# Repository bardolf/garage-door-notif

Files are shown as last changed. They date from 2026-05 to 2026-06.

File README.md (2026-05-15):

# Garage door notif

Battery-powered detekce otevřených garážových vrat v noci (22:00–06:00) přes ESP32 + MPU6050 + ntfy.sh push notifikace. Cílová životnost na 18650 baterii: **~1 rok mezi nabíjeními** (omezeno self-discharge baterky ~2–4 %/měsíc + kapacitní degradace + chlad v garáži, ne čistou spotřebou ESP).

**Dokumentace:**
- [`USAGE.md`](USAGE.md) — pro koncového uživatele (jak to funguje, co znamenají notifikace, FAQ)

---

## Use case

**Co řešíme:** Detekovat, jestli jsou garážová vrata **otevřená v noci mezi 22:00 a 06:00**, a poslat alert na mobil.

**Klíčový rozdíl proti motion detekci:** vrata mohou být otevřená už od 14:00 a zůstat tak — v 22:00 už žádný motion event nenastane. **Musíme polovat stav, ne čekat na změnu.**

**Design cíle:**
- Alert do ~5 min po 22:00, pokud jsou vrata otevřená
- Alert i během noci, pokud se otevřou
- Battery-powered, žádné kabelování ke garáži
- Životnost **~1 rok** mezi nabíjeními (realistický cíl, ne teoretické maximum)
- Žádný „false positive" z větru / vibrací

---

## Architektura

Timer-based polling (ne motion-driven). ESP probudí RTC každých 5 min, přečte tilt z MPU6050, rozhodne na základě času a stavu, případně pošle notifikaci, vrátí se do deep sleep.

```
COLD BOOT (power-on / RST)
   │
   ├─► WiFi + NTP sync
   ├─► MPU baseline capture (50 vzorků, průměr — předpoklad: vrata zavřená)
   ├─► Boot notifikace na ntfy.sh
   └─► ESP+MPU deep sleep, wake za 5 min
                    │
                    ▼
WAKE CYCLE (každých 5 min)
   │
   ├─► Wake MPU přes I²C (clear SLEEP bit, wait 30 ms)
   ├─► Read accel × 6 (zahod první, průměr ze zbylých 5)
   ├─► Spočti tilt vůči baseline (3D úhel)
   ├─► MPU zpět do SLEEP mode (5 µA)
   │
   ├─► Hystereze: open >60°, close <40° (stav v RTC mem)
   │
   ├─► Časová logika:
   │     ├─ 22:00-06:00 + open + rate limit OK (4 min) → URGENT alert
   │     ├─ hodina 21 + heartbeat dnes neodeslán      → daily heartbeat
   │     ├─ poslední NTP sync >24h                    → opportunistic refresh
   │     └─ MPU error queue má pendingy               → error report
   │
   ├─► Pokud potřeba WiFi: connect → ntp_sync (zadarmo) → poslat → disconnect
   └─► ESP+MPU deep sleep, wake za 5 min
```

### Klíčové principy

1. **Timer wake (RTC), ne motion wake (MPU INT)** — vrata stojí staticky, motion event se nestane.
2. **MPU drží v SLEEP mode (5 µA) mezi měřeními** — ESP probudí přes I²C jen na ~50 ms při wake.
3. **Hystereze + průměr** — proti vibracím / větru. První sample po wake je outlier (zahodit).
4. **Rate limiting alertů 4 min** — pri stuck-open vratech alert každý wake cyklus (~5 min), neoslepí appku ale informuje opakovaně.
5. **NTP sync 1× za 24 h + opportunistic** — pokaždé když už máme WiFi (alert/heartbeat), syncneme i čas zadarmo.
6. **State v RTC slow memory** — baseline, alert/heartbeat trackery, error queue, hysteresis stav přežívají deep sleep, ne power-off.
7. **Errors přes ntfy** — jediný komunikační kanál, takže senzor failures se queueují a posílají při příští WiFi příležitosti.

---

## Hardware

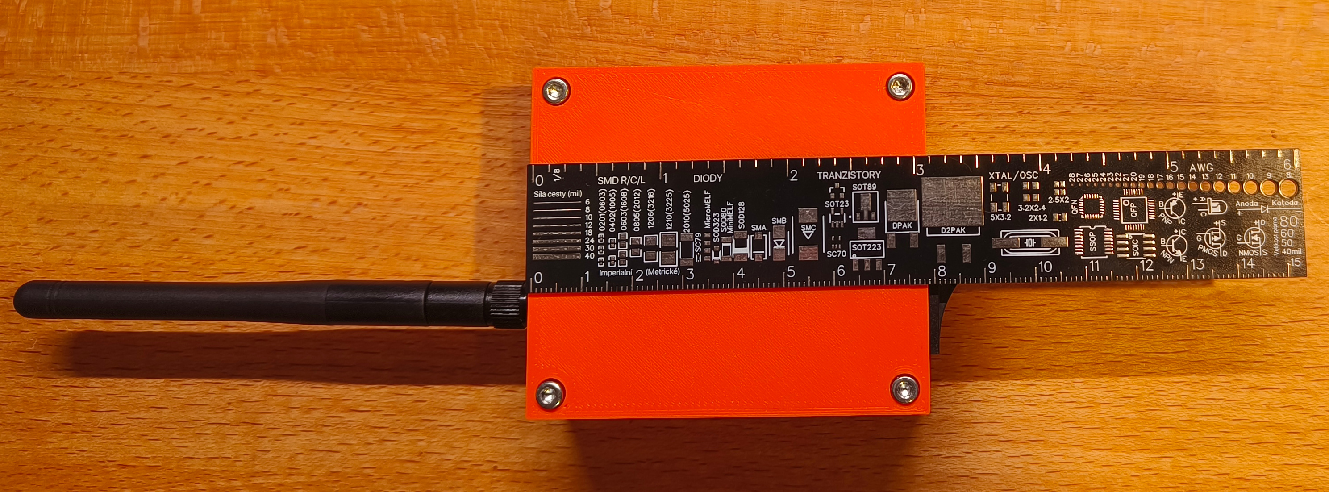
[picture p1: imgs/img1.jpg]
Hotová krabička s externí anténou vedle pravítka pro měřítko


*Hotové zařízení (varianta s externí anténou) — 3D tištěná krabička 7×8×3 cm, vlevo viditelná externí anténa 2,4 GHz na pigtailu.*

> **Pozor — LaskaKit ESP32-C3-LPKit v4 existuje ve dvou variantách:**
> 1. **S integrovanou PCB anténou** — plug-and-play, stačí samotná deska. Vhodné pokud AP je v rozumné vzdálenosti (~10 m, přes 1 zeď).
> 2. **S u.FL/IPEX konektorem pro externí anténu** — bez antény nepřijímá WiFi! Nutné dokoupit **pigtail U.FL ↔ SMA** + **externí anténu 2,4 GHz** (řádky níže v BOM). Větší dosah, vhodné kdy AP přes víc zdí nebo dál.
>
> Při objednávce ověřit kterou variantu máš — popis na LaskaKit produktové stránce nemusí být jednoznačný, podle revize. Pokud nevíš, podívej se na fotku desky: PCB anténa = klikatý měděný motiv u rohu modulu; externí varianta má malý stříbrný konektor.

### BOM

| Položka | Cena | Pozn. |
|---|---:|---|
| **[LaskaKit ESP32-C3-LPKit v4](https://www.laskakit.cz/laskkit-esp-12-board/)** (board ID `esp32-c3-devkitm-1`) | 298 Kč | ESP32-C3 (RISC-V), nativní USB-CDC bez externího USB-Serial čipu, on-board WS2812 NeoPixel RGB LED (GPIO9), JST-PH 2.0 + integrovaný LiPo charger, low-quiescent LDO se softwarovým `PERIPH_EN` switchem (GPIO4) pro perif. rail. Sleep proud naměřeno **19 µA** — viz [Spotřeba](#spotřeba). Antenna varianta — viz poznámka nad tabulkou. |
| **[Pigtail U.FL ↔ SMA female, 15 cm](https://www.laskakit.cz/pigtail-u-fl-sma-female--kabel-1-13mm--15cm/)** *(jen u externí antény)* | 38 Kč | Propojení on-board U.FL/IPEX konektoru s externí anténou přes SMA spoj. Nutné jen u varianty desky bez integrované PCB antény. |
| **[Anténa 2,4 GHz 10 cm SMA](https://www.laskakit.cz/antena-10cm-2-4g/)** *(jen u externí antény)* | 88 Kč | NiceRF SW2400-ZD115. Šroubuje se na pigtail. Lepší dosah než on-board PCB anténa — vhodné pokud je AP daleko nebo přes zdi. |
| **[GY-521 MPU6050 / MPU6500](https://www.laskakit.cz/arduino-gyroskop-a-akcelerometr-gy-521--mpu6050/)** (akcelerometr) | 98 Kč | 6-axis IMU, I²C adresa `0x68`, on-board 3,3 V LDO + 4,7 kΩ pull-upy na SDA/SCL. Silkscreen říká „MPU6050", v praxi často osazeno **MPU-6500** (WHO_AM_I=0x70) — firmware detekuje a akceptuje obě varianty. Zelená status LED na modulu odpájet (1,44 mA always-on). |
| **[LaskKit GeB Li-Ion 18650 1S1P 3,7 V 3200 mAh](https://www.laskakit.cz/geb-li-ion-baterie-1x18650-1s1p-3-7v-3200mah/)** | 188 Kč | 18650 cell s integrovanou ochranou (over-discharge / over-current). Nabíjí se přes USB-C C3-LPKit (on-board charger). JST-PH 2.0 konektor. |
| **Spínač / tlačítko v sérii s baterií** | ~20 Kč | Rozepíná napájení z baterie — slouží k vynucenému cold bootu (zachycení nové baseline po instalaci, viz boot notifikace). Bez fyzického přístupu k RST tlačítku po zavření krabičky. |
| **Šroubky (M3 + M2)** | ~20 Kč | 4× M3 imbus pro víko krabičky + 2× M2 self-tap pro ESP modul + 2× M2 pro MPU. |
| **3D tištěná krabička** | ~30 Kč | OpenSCAD model `3dprint/`, průzor ve víku pro NeoPixel indikaci. MPU musí být pevně přichycena k vratům, ne k rámu (jinak měří pohyb rámu, ne dveří). Cena materiálu (PETG, ~60 g × ~0,5 Kč/g). |

Propojení MPU ↔ ESP: 4 drátky (VCC, GND, SDA, SCL) připájené přímo na pájecí pady — bez DuPont konektoru, pevnější vůči vibracím.

**Celkem:** ~660 Kč (s integrovanou PCB anténou) / ~790 Kč (s externí anténou).

### Pin allocation (LaskaKit ESP32-C3-LPKit v4 — aktuální)

| GPIO | Funkce | Pozn. |
|---|---|---|
| 0 | ADC — Vbat sense | on-board divider ×1.769, použít `analogReadMilliVolts()` (viz silkscreen v4.0) |
| 4 | `PERIPH_EN` — power switch perif. rail | HIGH = napájena MPU + NeoPixel; LOW = oboje off. `gpio_hold_en` pro persistenci přes deep sleep |
| 6 | I²C SDA → GY-521 SDA | volný GPIO bez kolize se strapping/USB/UART |
| 7 | I²C SCL → GY-521 SCL | volný GPIO bez kolize |
| 9 | on-board WS2812 NeoPixel (RGB LED) | jediný indikátor stavu; GPIO9 by jinak byl BOOT strapping, na C3-LPKit obsazený LED |
| 20 | UART0 RX | volné, lze využít pro externí USB-UART monitor při battery měření |
| 21 | UART0 TX | volné, lze využít pro externí USB-UART monitor při battery měření |

Obsazené čipem / deskou: USB-C přes nativní USB-CDC (GPIO18/19), 32 kHz krystal (interní RC), Flash (GPIO11–17 interní v ESP32-C3-MINI-1 modulu).

### Zapojení MPU6050 / MPU6500 ↔ ESP32-C3-LPKit v4

GY-521 modul napájíme **z PERIPH_EN railu** (přes GPIO4 power switch) — v deep sleep tak MPU dostane 0 V a nemusíme ji explicitně uspávat přes I²C kvůli sleep proudu.

| GY-521 pin | C3-LPKit pin | Pozn. |
|---|---|---|
| VCC | 3V3 | jakýkoli 3V3 pin na headeru — všechny jsou za PERIPH_EN switchem |
| GND | GND | jakýkoli GND pin |
| SDA | GPIO6 | I²C data |
| SCL | GPIO7 | I²C clock |
| AD0 | nezapojeno | → I²C adresa **0x68** (default pull-down na GY-521 modulu) |
| INT | nezapojeno | timer wake, ne motion interrupt |
| XCL, XDA | nezapojeno | aux I²C master pro magnetometr — nepoužívá se |

Pull-up rezistory pro I²C jsou integrované na GY-521 modulu (4.7 kΩ na SDA i SCL), externí netřeba.

**MPU chip:** silkscreen modulů obvykle říká `MPU6050`, ale GY-521 se prodávají s oběma — MPU-6050 (WHO_AM_I=0x68) i MPU-6500 (0x70). Firmware akceptuje 0x68/0x70/0x71/0x73 (MPU-6050/6500/9250/9255), register layout je v naší podmnožině (accel + temp) kompatibilní.

### Sestavení v krabičce

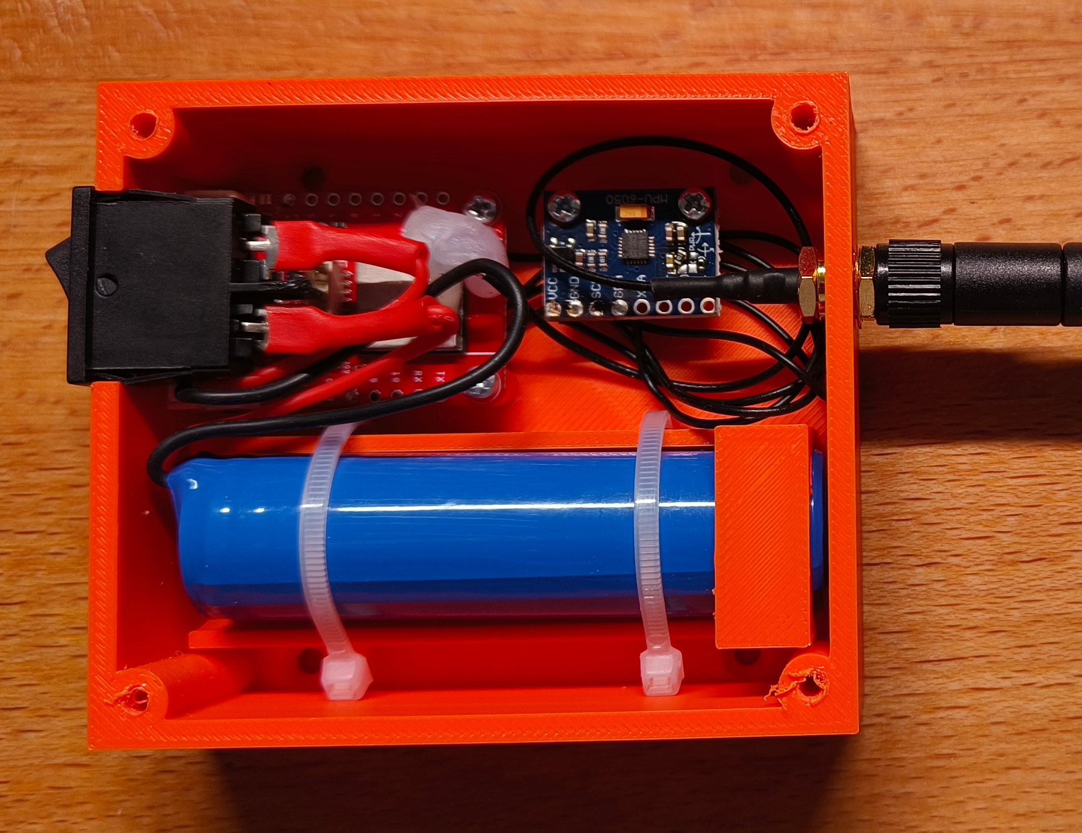
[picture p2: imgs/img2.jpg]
Vnitřek krabičky — ESP modul, MPU senzor, 18650 baterie, spínač, U.FL pigtail


Layout uvnitř (z fotky):
- **Vlevo nahoře:** kolébkový spínač v -X stěně, pájené přímo na baterii (rozpojuje +pól)
- **Vlevo nahoře vedle:** ESP32-C3-LPKit přišroubovaný k +X stěně, USB-C přístupný zvenku
- **Vpravo nahoře:** GY-521 MPU modul přišroubovaný na +Y stěnu, 4 pájené drátky do ESP
- **Vpravo střed:** U.FL pigtail s SMA bulkhead konektorem do +X stěny, externí anténa zvenku
- **Dole:** 18650 baterie v U-kanálu, fixovaná dvěma zip-ties přes víko

---

## Jak to spustit

| Cíl | Příkaz |
|---|---|
| **Finální app** (default) | `pio run -t upload -t monitor` |
| Jen build (bez upload) | `pio run` |
| Jen monitor (bez flash) | `pio device monitor` |
| Vyčistit build cache | `pio run -t clean` |

Port: `/dev/ttyUSB0`. Baud: 115200.

Debug moduly a vývojářské nástroje viz sekce [Debug — vývojářské nástroje](#debug--vývojářské-nástroje) na konci.

---

## Struktura projektu

```
src/main.cpp              ← finální integrovaná aplikace (env: app)
debug/
  ntfy/main.cpp           ← WiFi + NTP + ntfy + Vbat status loop
  tilt/main.cpp           ← MPU6050 baseline + tilt monitoring
  sleep/main.cpp          ← ESP+MPU deep sleep + RTC mem
include/
  secrets.h               ← WiFi heslo, ntfy topic (NEVERZOVÁNO)
  secrets.h.example       ← šablona
platformio.ini            ← envs: app (default), tilt, ntfy, sleep
USAGE.md                  ← uživatelský návod
```

Filozofie: každý debug modul je samostatně flashovatelný firmware, izolovaně testuje jednu věc. Finální `src/main.cpp` skládá funkce z odladěných modulů.

---

## Co dělá hlavní app

State persistovaný přes deep sleep v RTC slow memory (`RTC_DATA_ATTR`):
boot_count, baseline vector, door_was_open, last_alert_unix, last_heartbeat_yday, last_ntp_unix, error queue (count + last message).

**Cold boot** (po zapnutí / RST):
1. WiFi connect + NTP sync (CET/CEST automaticky přes POSIX TZ)
2. MPU6050 baseline capture (50 vzorků, průměr, předpoklad zavřených vrat)
3. Boot notifikace nebo error report na ntfy.sh
4. ESP+MPU deep sleep, wake za 5 min

**Wake cyklus** (každých 5 min) — viz [Architektura](#architektura) výše.

Detaily v hlavičce `src/main.cpp`.

### Typy notifikací

| Událost | Title | Priority | Tag |
|---|---|---|---|
| Cold boot | Hlidac garazovych vrat aktivni | default | rocket |
| Vrata otevřená 22-06 | GARAZ OTEVRENA! | **urgent** | rotating_light |
| Denní kontrola 21:00 | Garaz - denni kontrola | low | white_check_mark / yellow_circle / battery |
| Senzor / baseline error | Hlidac vrat - CHYBA | high | warning |

Detaily a uživatelský pohled v [`USAGE.md`](USAGE.md).

---

## ntfy.sh

- Topic: `milan-garaz-2026-x8kf3pq7vn` (random, regenerovat před deploymentem)
- Free tier: 60 burst / replenish 1 každých 5 s = ~17k/den max
- Web subscriber pro test bez appky: `https://ntfy.sh/<topic>`
- Server-side history (12 h): `curl 'https://ntfy.sh/<topic>/json?poll=1&since=1h'`

```bash
# poslat testovací zprávu
curl -d "test" -H "Title: Test" ntfy.sh/milan-garaz-2026-x8kf3pq7vn

# přečíst historii za poslední hodinu
curl -s "https://ntfy.sh/milan-garaz-2026-x8kf3pq7vn/json?poll=1&since=1h"
```

---

## Spotřeba

### Teoretická predikce

| Komponenta | Spotřeba | Pozn. |
|---|---|---|
| ESP32-C3 deep sleep | ~5–10 µA | datasheet, sám čip |
| MPU6050/6500 — rail off | 0 µA | PERIPH_EN=LOW odřízne |
| Wake event (no WiFi) | ~25 mA × ~5 s | MPU read + tilt compute |
| Alert / heartbeat (s WiFi) | ~80 mA × 5 s | NTP + HTTP POST |

**Denní budget** (předpoklad: 288 wake/den, ~5 alert/heartbeat events/den):

| Položka | Výpočet | Energie/den |
|---|---|---|
| ESP32-C3 deep sleep | 24 h × 19 µA × 3,3 V | 1,5 mWh |
| 288 wake × 5 s | 25 mA × 3,3 V × 1440 s | 33 mWh |
| 5 WiFi events × 5 s | 80 mA × 3,3 V × 25 s | 1,8 mWh |
| **Σ celkem** | | **~36 mWh/den** |

**Teoretické maximum** (čistě výpočet ze spotřeby, ESP32-C3 + odpájené LED):

| Baterie | Kapacita | Teoretická životnost |
|---|---|---|
| 1000 mAh LiPo | ~3,7 Wh | ~1,7 roku |
| **18650 3200 mAh** ([LaskKit GeB](https://www.laskakit.cz/geb-li-ion-baterie-1x18650-1s1p-3-7v-3200mah/)) | ~11,8 Wh | ~5,5 let |

**Realistický cíl: ~1 rok mezi nabíjeními** na 18650. Teoretické maximum je výrazně optimistické, reálnou životnost limitují:

- **Self-discharge baterie** ~2–4 %/měsíc = ~25–40 % kapacity ztracené čistě sezením za rok
- **Kapacitní degradace Li-Ion** ~3–5 %/rok stárnutím (i bez cyklování)
- **Chlad v zimní garáži** (0 °C) snižuje efektivní kapacitu o ~20–30 %
- **Protection cutoff baterky** zastaví ESP při ~3,0 V, nevyužije se posledních ~5–10 % kapacity
- **Reálné wake events** typicky 2–3× teoretická hodnota (retries, error events, NTP timeouty)

➜ Plánovat **nabíjení 1× ročně** je realistický cíl. „5,5 let" je horní strop matematiky, ne reálné očekávání.

### Naměřené hodnoty (LaskaKit ESP32-C3-LPKit v4)

Setup: baterie přes JST → multimetr v sérii → C3-LPKit v4 + GY-521 (zelená LED odpájena, MPU napájena přes `PERIPH_EN` rail = GPIO4). Firmware: `debug/c3sleep/main.cpp` (`AWAKE_HOLD_MS = 5000`, `SLEEP_DURATION_S = 30`, NeoPixel brightness 40/255 jasně červená). `gpio_hold_en(GPIO4)` drží `PERIPH_EN=LOW` přes deep sleep → MPU a NeoPixel rail odpojený.

| Konfigurace | Active hold | Deep sleep | Pozn. |
|---|---|---|---|
| C3-LPKit v4 + GY-521 (NeoPixel on) | **24 mA** | **19 µA** | MPU napájena z PERIPH_EN, neuspána přes I²C |

Active proud (24 mA) = ESP32-C3 active ~10 mA + NeoPixel ~10 mA + MPU6500 active ~4 mA. Při deep sleep `PERIPH_EN=LOW` odřízne NeoPixel i MPU rail → vidíš čistě C3 + LDO + charger IC quiescent.

Sleep mAh/den: **19 µA × 24 h = 0,46 mAh/den**. Při 18650 3200 mAh teoretické maximum (jen sleep, bez wake events) ~7 000 dní (~19 let) — v praxi limitováno self-discharge baterie a kapacitní degradací; viz Wake interval tabulka níže.

### Wake interval vs. životnost

Otázka: jak se mění životnost, pokud probouzím častěji? Předpoklad: počet odeslaných zpráv (alerty + heartbeat) zůstává konstantní ~5/den, mění se jen frekvence MPU read cyklů bez WiFi.

**Vstupy** (z naměřených / teoretických hodnot výše):
- Wake bez WiFi: 50 mA × 0,2 s = **0,00278 mAh/wake**
- WiFi event: 80 mA × 5 s = 0,111 mAh × 5/den = **0,56 mAh/den**
- Sleep ESP32-C3 + MPU rail off (PERIPH_EN=LOW) **naměřeno 19 µA** × 24 h = **0,46 mAh/den**
- Self-discharge 18650 (3 %/měs ze 3200 mAh) = **3,2 mAh/den**
- Kapacita: 3200 mAh

| Wake int. | Wakes/den | Wake E [mAh] | Sleep [mAh] | WiFi [mAh] | Self-disch. [mAh] | **Σ/den** | **Životnost** |
|---:|---:|---:|---:|---:|---:|---:|---:|
| 1 min  | 1440 | 4,00 | 0,48 | 0,56 | 3,2 | **8,24** | ~388 dní (~1,06 r) |
| 2 min  | 720  | 2,00 | 0,48 | 0,56 | 3,2 | **6,24** | ~513 dní (~1,40 r) |
| 5 min  | 288  | 0,80 | 0,48 | 0,56 | 3,2 | **5,04** | ~635 dní (~1,74 r) |
| 10 min | 144  | 0,40 | 0,48 | 0,56 | 3,2 | **4,64** | ~690 dní (~1,89 r) |
| 20 min | 72 | 0,20 | 0,48 | 0,56 | 3,2 | **4,44** | ~721 dní (~1,98 r) |
| 30 min | 48 | 0,13 | 0,48 | 0,56 | 3,2 | **4,37** | ~732 dní (~2,00 r) |

**Insight: self-discharge ~3,2 mAh/den je floor, který nelze podlézt.** Sleep + zprávy přidají dalších ~1,0 mAh/den (taky fixní). Variabilní část = wake events:

- **5 min** (aktuální): 0,80 mAh/den, +25 % nad floor — rozumný kompromis
- **2 min**: 2,0 mAh/den, +62 % nad floor — znatelný hit (cena: −24 % životnosti vs. 5 min)
- **1 min**: 4,0 mAh/den, +125 % nad floor — wake events už dominují nad samovybíjením

➜ Mezi „self-discharge převažuje" a „wake events převažují" je hranice **někde mezi 2 a 5 min wake intervalem**. Pod 5 min jdeme rapidně dolů, nad 5 min už další zpomalování přínos nedává (rozdíl 5 → 30 min je jen ~15 % životnosti).

**Caveats:** kalkulace neuvažují kapacitní degradaci (~3–5 %/r), chlad v zimě (−20–30 % efektivní kapacity) ani stuck-open scénář (vrata nechaná otevřená přes noc → ~120 alertů přes rate-limit → ~13 mAh extra v jedné noci). Reálná životnost bude o 20–40 % nižší.

Při naměřeném sleep proudu 19 µA (= 0,46 mAh/den) je projekce realistická — wake interval má reálný dopad: 5 min = 1,74 r, 30 min = 2,00 r. Self-discharge zůstává nepřekročitelný floor.

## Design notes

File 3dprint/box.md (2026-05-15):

# box.scad — reference notes

Working notes for `box.scad`. The .scad file has inline comments on every parameter; this doc covers the things that aren't obvious from reading parameter declarations: **design intent, parameter dependencies, and how to change common things.**

## What's in the box

Spodek (`base`):
- **Battery cradle** along -Y half of the inner space, X axis. 64 mm open U-channel + 6 mm closed ring at +X end (battery stop).
- **4 lid screw posts** in corners (M3 self-tap, Ø 7 mm, pilot 2.5 mm).
- **ESP module mounts**: 2 standoffs (Ø 5, h 5, 2.1 mm pilot — M2 self-tap; original design byl pro M2.5, M2 v PETG sedí pohodlně) on +X edge of PCB + 1 central under-support (Ø 4, h 5) on -X (USB-C) edge.
- **MPU6050 standoffs**: 2 on +Y edge of PCB, shifted toward +Y wall.
- **USB-C cutout** in -X wall, centered on ESP Y.
- **Antenna hole** Ø 6.5 mm in +X wall (opposite USB-C), Z offset +5 mm above USB-C center — sedí na závit RP-SMA / SMA bulkhead konektoru.
- **Rocker switch slot** in -X wall, OPEN at top (switch slides in from above). Y offset +2 mm from USB-C center toward +Y edge.
- **Zip-tie tunnels** through cradle at 25 % and 75 % of battery length.
- **4 floor mounting holes** (Ø 3 mm wood screws to garage door, countersunk inside).

Víko (`lid`):
- Flat plate with 4 counterbored holes for M3 socket-cap (imbus) screws.
- **Lid half-cradle** (10 mm long, centered along battery length): mirrors base U-channel in the middle of the cell, drží baterii dolů v U-kanálu. Konce baterie zůstávají volné pro vodiče.
- ESP pressure pin: **odstraněn** — kolidoval by s rocker switch v -X stěně.

Build:
```
openscad -D 'part="base"' -o box-base.stl box.scad
openscad -D 'part="lid"'  -o box-lid.stl  box.scad
```
Default `part="both"` renders side-by-side preview for GUI use.

## Parameter dependencies (must hold)

These are not enforced by the .scad — if you change a parameter, verify these still hold or you'll get clashes / non-printable geometry:

1. **`inner_z` ≥ `cradle_under + batt_dia + batt_clearance + cradle_ring_ceil + 0.5`**
   — otherwise the +X ring sticks above the box top and lifts the lid. Currently `inner_z = batt_dia + 3.5` gives 0.5 mm clearance.
2. **`inner_y` ≥ `mod_y1_esp + post_intrude + 0.5`**
   — keeps the +Y corner posts from colliding with the ESP module.
3. **Zip-tie tunnel X positions** (25 / 75 % of battery length) must be clear of the centered `lid_cradle_len` (at 50 %) and the closed ring (+X end). With `batt_len = 70` a `lid_cradle_len = 10`, tunnel centers are at 22.5 / 57.5 mm a lid cradle obsazuje 35–45 mm → ~12.5 mm mezery k oběma tunelům.
4. **Lid cradle Y span = base cradle Y span** (both use `cradle_w` via `batt_axis_y_g`). If you reposition the battery in Y, both follow automatically.
5. **`screw_inset + screw_post_dia/2 ≤ wall + post_intrude_clearance`** — corner posts must remain attached to the walls. Currently `5 + 3.5 - 3 = 5.5 mm` intrusion into inner space; cradle_y0 (= 6) and other features are designed around this.
6. **Battery in cradle: clearance with -Y corner posts requires `cradle_y0 ≥ post_intrude + 0.5`** — i.e. cradle has to start 6 mm from inner -Y wall to not collide with corner posts.

## How to change common things

| You want to… | Change |
|---|---|
| Use a 14500 / different cell | `batt_len`, `batt_dia`. inner_z, inner_y will recompute. |
| Make box wall thicker/thinner | `wall` (cradle Y_offset, corner post intrusion will follow) |
| Shift MPU closer to battery | `mpu_y1 = mod_y0 + mpu_w` (was `mod_y1_esp`) |
| Use socket-cap vs flat-head lid screws | `lid_cbore_dia` and `lid_cbore_depth` (currently set for socket cap; for flat head use cone `cylinder(d1=clear, d2=head_dia, h=...)`) |
| Move rocker switch | `switch_y_offset` (along -X wall) |
| Resize rocker switch | `switch_w`, `switch_h` |
| Skip USB-C cutout (no USB exposure) | comment out the USB-C subtraction block in `base()` |
| Resize antenna hole (jiný SMA gauge) | `ant_hole_dia` (default 6.5 mm pro RP-SMA bulkhead) |
| Posunout antenni otvor vyse / nize | `ant_hole_z_lift` (default 5 mm nad USB-C Z center) |
| Different battery retention | Lid cradle (`lid_cradle_len`) and/or zip-tie tunnels (`zip_x1_g`, `zip_x2_g`) — both currently active |
| Reposition module screws (after measuring actual board) | `esp_hole_sp`, `esp_hole_inset`, `mpu_hole_sp`, `mpu_hole_inset` |
| Reposition ESP under-support (single pillar) | `esp_support_dx_from_mount`, `esp_support_dia`, `esp_support_h` |
| Floor mounting holes elsewhere | `mount_x_offset`, `mount_y_offset` (from outer wall) |

## Things marked REMEASURE

ESP-related dimensions are MEASURED from a real board. The rest are educated guesses; measure and update as needed:

- `usb_w`, `usb_h` (12 × 6 mm) — USB-C cutout; widen if needed for thick cables
- `switch_w`, `switch_h` (20 × 7 mm) — rocker switch cutout

## Assembly procedure

1. Box base, lid off, modules NOT yet attached.
2. Screw the base onto the garage door through the 4 floor holes (3 mm wood screws, countersunk inside).
3. Solder battery wires (no holder; bare-wire 18650).
4. Drop battery into cradle: tilt with +X end first, insert into closed ring section, then lower -X end into the U-channel.
5. Solder wires to rocker switch (outside the box), then slide switch into the slot in -X wall from above.
6. Optionally: thread one or two zip-ties through the tunnels, over the battery, lock on -Y side.
7. Screw ESP module to its two +X-edge standoffs (M2 self-tap, ~5–6 mm length).
8. Screw MPU6050 to its two +Y-edge standoffs (M2 self-tap).
9. Place lid (lid half-cradle sedí ve středu baterie). Tighten 4 M3 cap screws.

## Print notes

- **Material**: PETG (used for current build, ~60 g per set base+lid). PETG drží lépe ohyb ring sekce + lid cradle. PLA jde taky, ale je křehčí v tenkých přesahech.
- **Layer height**: 0.2 mm fine for most parts; closed ring section at +X has a ~10 mm bridge at the top (battery diameter); use bridging-friendly settings.
- **Orientation**:
  - Base: flat on bed (floor down). No supports needed except inside the closed ring at +X end (small bridge, usually OK without).
  - Lid: top side up (lid cradle protrudes from underside; print needs to be flipped from default OpenSCAD render — features sticking up).
- **Walls**: 3+ perimeters recommended; screw posts and standoffs benefit from solid extrusion.
- **First print**: do a draft (0.3 mm, 2 perimeters) of just the base to verify all the components fit before printing final.

## Known TODOs / future tweaks

- Battery insertion is angled (+X end first, then drop -X end). Lid cradle is added separately, so insertion stays the same as without it.
- Zip-tie head: ensure 6+ mm of strip free between -Y wall and cradle for the head to sit; current = 6 mm (cradle_y0). If you make the cradle thicker (`cradle_side`), this shrinks.
- ~~**Status LED window in lid**~~: hotovo — průchozí Ø 4 mm díra v lid plate, řízeno parametry `led_hole_dia`, `led_x_from_mount`, `led_y_from_pcb_inner_edge`. Pozice odměřena z reálné desky.

## Box dimensions (current defaults)

- Outer: **80 × 70.1 × 28 mm** (base 25 mm + lid 3 mm)
- Inner: 74 × 64.1 × 22 mm

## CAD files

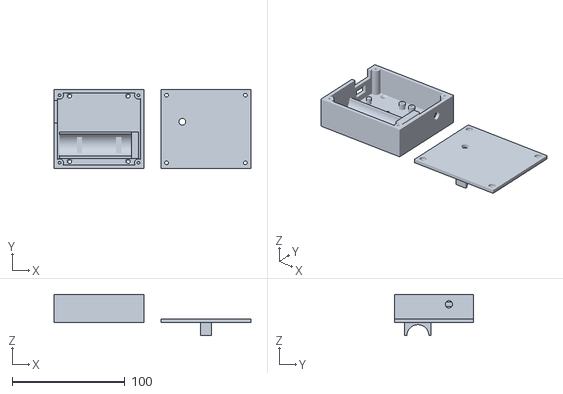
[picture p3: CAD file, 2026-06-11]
3dprint/box.stl
175.0 x 70.1 x 36.8

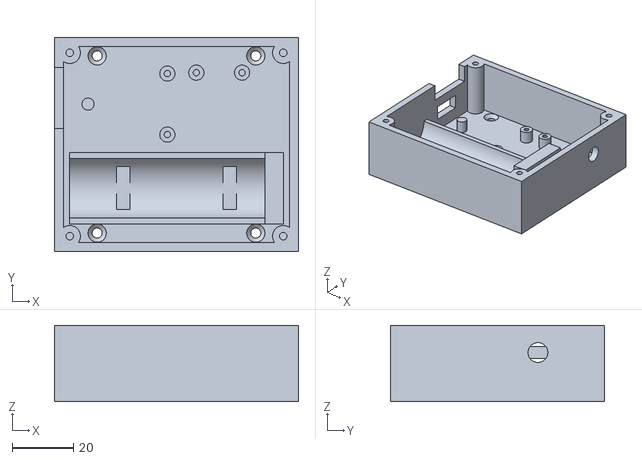
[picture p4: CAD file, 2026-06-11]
3dprint/box-base.stl
80.0 x 70.1 x 25.0

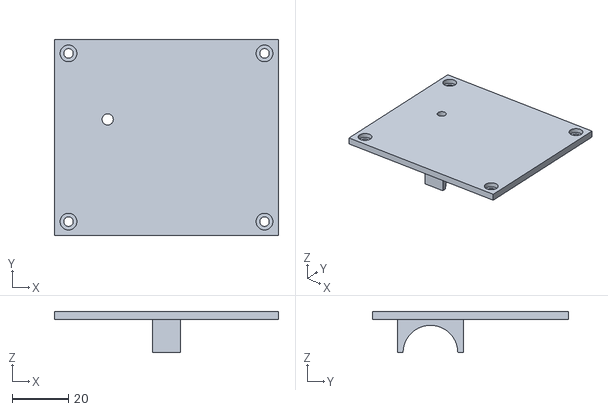
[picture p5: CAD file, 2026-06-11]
3dprint/box-lid.stl
80.0 x 70.1 x 14.8

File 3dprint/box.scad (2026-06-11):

// box.scad — Enclosure for garage-door-notif
//   18650 battery (lower row), ESP module + MPU6050 (upper row, side by side).
//   M3 self-tap screws into 4 corner posts; flat-head countersunk in lid.
//
// Render in CLI:
//   openscad -D 'part="base"' -o box-base.stl box.scad
//   openscad -D 'part="lid"'  -o box-lid.stl  box.scad

part = "both";  // "base" | "lid" | "both"  (override with -D)

// ===== shell =====
wall          = 3.0;
floor_thk     = 3.0;
lid_thk       = 3.0;

// ===== battery (18650) =====
batt_len           = 70.0;
batt_dia           = 18.5;
batt_clearance     = 0.5;     // radial slop
batt_ring_len      = 6.0;    // closed ring section at far end (battery stop)
cradle_side        = 2.0;     // side wall outside battery diameter
cradle_under       = 1.0;     // material between cradle bottom and box floor
cradle_ring_ceil   = 1.5;     // material above battery in ring section

// ===== ESP module =====
esp_l           = 34.5;       // along X, USB-C on -X short edge
esp_w           = 25.6;       // along Y
esp_hole_sp     = 20.0;       // hole spacing on +X short edge (along Y) — MEASURED
esp_hole_inset  = 2.5;        // hole inset from +X edge
esp_pcb_thk     = 1.6;

// ===== MPU6050 =====
mpu_l           = 21.0;       // along X
mpu_w           = 15.0;       // along Y
mpu_hole_sp     = 15.0;       // hole spacing on +Y long edge (along X) — MEASURED
mpu_hole_inset  = 2.5;        // hole inset from +Y edge

// ===== module standoffs (M2 self-tap; pilot 2.1 z puvodniho M2.5 designu — v PETG drzi i M2) =====
standoff_dia        = 5.0;
standoff_h          = 5.0;
standoff_pilot      = 2.1;
standoff_pilot_depth = 5.0;

// ===== lid screws (M3 socket cap / imbus, self-tap into corner posts) =====
screw_post_dia      = 7.0;
screw_post_pilot    = 2.5;
screw_post_depth    = 12.0;
screw_inset         = 5.0;    // from outer corner to screw axis
lid_clear           = 3.4;    // through hole for M3 shaft
lid_cbore_dia       = 6.0;    // counterbore Ø for M3 cap head (head Ø 5.5)
lid_cbore_depth     = 2.0;    // partial recess (M3 cap head is 3.0 mm; ~1 mm sticks out)

// ===== USB-C cutout (in -X wall, centered on ESP USB-C) =====
usb_w           = 12.0;
usb_h           = 6.0;

// ===== anteni otvor (v +X stene, protilehla od USB-C) =====
// Y zarovnano s USB-C (ne v geometrickem stredu +X steny).
// Z posunuto vys nez USB-C — bulkhead konektor potrebuje misto pro matku/podlozku
// na vnitrni strane a aby byl dal od podlahy / baterie.
// 6.2 mm sedi na zavit RP-SMA / SMA bulkhead konektoru.
ant_hole_dia    = 6.5;
ant_hole_z_lift = 5.0;   // o kolik vyse nez usb_z_center (mm)

// ===== floor mounting holes (4× Ø 3 mm wood screw, countersunk inside the box) =====
// Box is screwed to the garage door from the inside (lid off, modules removed).
mount_screw_clear = 3.3;       // shaft clearance hole
mount_cs_dia      = 6.0;       // countersink Ø at inner floor surface
mount_cs_depth    = 1.5;       // depth (suits 90° flat-head wood screw)
mount_x_offset    = 14.0;      // hole center distance from outer X wall
mount_y_offset    = 6.0;       // hole center distance from outer Y wall

// ===== rocker switch (slot in -X wall next to USB-C, OPEN at top) =====
// Switch body protrudes in +X direction into the module zone (above battery),
// so even a deep switch body won't collide with the 18650.
// Solder wires first, then drop switch into the slot from above; lid closes it.
switch_w        = 20.0;       // cutout width along Y (along the -X wall)
switch_h        = 7.0;        // cutout height along Z (slot opens to top)
switch_y_offset = 2;          // shift from USB-C Y center (mm); + = toward +Y (k okraji)

// ===== lid half-cradle, centered along battery length =====
// Posunuto do stredu baterie (puvodne na -X konci), aby nekolidovalo s vodici
// na obou koncich clanku. Drzi clanek dolu v U-kanalu.
lid_cradle_len   = 10.0;

// ===== variant C: zip-tie tunnels through cradle (under battery) =====
zip_tunnel_w     = 4.5;       // X width (zip-tie body)
zip_tunnel_h     = 3.0;       // Z height
zip_tunnel_floor_gap = 0.5;   // gap above the box floor where the tunnel bottom sits

// ===== ESP under-support (single central pillar, USB-C side, non-threaded) =====
esp_support_dia            = 4.0;   // MEASURED
esp_support_h              = 5.0;   // same as mounting standoff_h — MEASURED
esp_support_dx_from_mount  = 26.0;  // X dist from ESP mount hole (toward USB-C) — MEASURED

// ESP lid pressure pin: ZRUSENO — kolidoval by s rocker switch v -X stene.

// ===== LED viewing hole in lid (NeoPixel on ESP module shines through) =====
led_hole_dia              = 6.0;   // priezor pro indikacni RGB LED
led_x_from_mount          = 18.0;  // X dist from ESP mount-hole line (toward USB-C) — MEASURED
led_y_from_pcb_inner_edge = 6.0;   // Y dist from ESP PCB edge nearest to battery — MEASURED

// ===== gaps =====
mod_gap_y       = 3.0;        // cradle <-> modules
mod_gap_x       = 4.0;        // ESP <-> MPU

$fa = 2; $fs = 0.4;
EPS = 0.01;

// ===== derived layout (inner coordinates) =====
// post_intrude: how far a corner post sticks into the inner cavity
post_intrude = screw_inset + screw_post_dia/2 - wall;

cradle_y0    = post_intrude + 0.5;
cradle_w     = 2*cradle_side + 2*batt_clearance + batt_dia;
cradle_y1    = cradle_y0 + cradle_w;
batt_axis_z  = cradle_under + batt_dia/2;

mod_y0       = cradle_y1 + mod_gap_y;
mod_y1_esp   = mod_y0 + esp_w;
// MPU shifted to +Y side of module zone (flush with ESP +Y edge) — gives more
// wire room between battery and MPU, and offsets the standoffs from the middle.
// To bias MPU toward the battery instead, set mpu_y1 = mod_y0 + mpu_w.
mpu_y1       = mod_y1_esp;
mpu_y0       = mpu_y1 - mpu_w;

esp_x0       = 2.0;
esp_x1       = esp_x0 + esp_l;
mpu_x0       = esp_x1 + mod_gap_x;
mpu_x1       = mpu_x0 + mpu_l;

esp_hole_x   = esp_x1 - esp_hole_inset;
esp_hole_y1  = mod_y0 + (esp_w - esp_hole_sp)/2;
esp_hole_y2  = esp_hole_y1 + esp_hole_sp;

mpu_hole_y   = mpu_y1 - mpu_hole_inset;
mpu_hole_x1  = mpu_x0 + (mpu_l - mpu_hole_sp)/2;
mpu_hole_x2  = mpu_hole_x1 + mpu_hole_sp;

inner_x = max(batt_len + 4, mpu_x1 + 2);
inner_y = mod_y1_esp + post_intrude + 0.5;
inner_z = batt_dia + 3.5;   // 1 mm clearance over the +X ring section + 0.5 mm to lid

outer_x      = inner_x + 2*wall;
outer_y      = inner_y + 2*wall;
outer_z_base = inner_z + floor_thk;

// USB-C placement (height = top of PCB + connector half-height)
usb_z_center = floor_thk + standoff_h + esp_pcb_thk + 1.5;
usb_y_center = wall + mod_y0 + esp_w/2;

// Battery axis in global coords (for lid cradle + zip-tie tunnels)
batt_x_start_g = wall + 2;
batt_axis_y_g  = wall + cradle_y0 + cradle_w/2;
batt_axis_z_g  = floor_thk + batt_axis_z;
batt_top_z_g   = batt_axis_z_g + batt_dia/2;
// zip-tie tunnel X positions along battery length (5 mm clear of lid cradle / +X ring)
zip_x1_g       = batt_x_start_g + batt_len * 0.25;
zip_x2_g       = batt_x_start_g + batt_len * 0.75;

// ESP under-support (single pillar on ESP Y center)
esp_center_y_g   = wall + mod_y0 + esp_w/2;
esp_support_x_g  = wall + esp_hole_x - esp_support_dx_from_mount;

// LED viewing hole (through lid, above NeoPixel on ESP module)
led_hole_x_g     = wall + esp_hole_x - led_x_from_mount;
led_hole_y_g     = wall + mod_y0 + led_y_from_pcb_inner_edge;

// ===== modules =====

module battery_cradle() {
  open_len = batt_len - batt_ring_len;

  // Open U-channel: top sliced off at battery equator
  difference() {
    cube([open_len, cradle_w, batt_axis_z]);
    translate([-EPS, cradle_w/2, batt_axis_z])
      rotate([0, 90, 0])
        cylinder(d = batt_dia + 2*batt_clearance, h = open_len + 2*EPS);
  }

  // Closed ring: full cylinder cavity, encloses far end of battery
  ring_top_z = batt_axis_z + batt_dia/2 + batt_clearance + cradle_ring_ceil;
  translate([open_len, 0, 0])
    difference() {
      cube([batt_ring_len, cradle_w, ring_top_z]);
      translate([-EPS, cradle_w/2, batt_axis_z])
        rotate([0, 90, 0])
          cylinder(d = batt_dia + 2*batt_clearance, h = batt_ring_len + 2*EPS);
    }
}

module standoff() {
  difference() {
    cylinder(d = standoff_dia, h = standoff_h);
    translate([0, 0, standoff_h - standoff_pilot_depth + EPS])
      cylinder(d = standoff_pilot, h = standoff_pilot_depth);
  }
}

module corner_post() {
  difference() {
    cylinder(d = screw_post_dia, h = inner_z);
    translate([0, 0, inner_z - screw_post_depth + EPS])
      cylinder(d = screw_post_pilot, h = screw_post_depth);
  }
}

module lid_screw_hole() {
  translate([0, 0, -EPS])
    cylinder(d = lid_clear, h = lid_thk + 2*EPS);
  translate([0, 0, lid_thk - lid_cbore_depth])
    cylinder(d = lid_cbore_dia, h = lid_cbore_depth + EPS);
}

// ===== parts =====

module base() {
  difference() {
    union() {
      // Hollow shell
      difference() {
        cube([outer_x, outer_y, outer_z_base]);
        translate([wall, wall, floor_thk])
          cube([inner_x, inner_y, inner_z + EPS]);
      }
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

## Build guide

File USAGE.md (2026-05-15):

# Garážový hlídač — uživatelský návod

> Tenhle návod je psaný pro běžného uživatele, ne pro techniky.
> Vysvětluje co zařízení dělá, jaké zprávy budete dostávat a co s nimi.

---

## Co to je a co to dělá

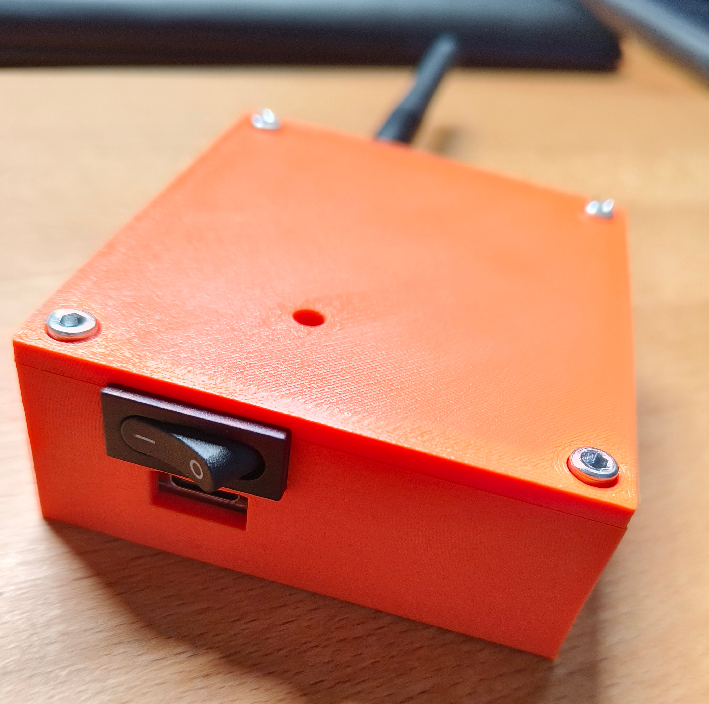
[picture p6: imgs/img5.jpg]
Hotová krabička s kolébkovým spínačem a externí anténou


V garáži je malé zařízení (ESP32 + senzor náklonu) připevněné k vratům. Běží na baterii, která vydrží **dlouho** (řádově měsíce až roky podle typu baterie).

**Jeho jedinou prací je hlídat: jsou vrata otevřená v noci?**

Pokud ano (mezi **22:00 a 06:00**, nebo dle nastavení), pošle vám okamžitou notifikaci na mobil. Mimo tuto dobu vás zařízení neotravuje — předpokládá se, že přes den s vraty pracujete normálně.

Notifikace chodí přes službu **ntfy.sh** (free, žádný účet, jen appka v telefonu).

---

## První nastavení (instalace)

Zařízení po prvním zapnutí spustí konfigurační WiFi „hotspot" — připojíte se k němu telefonem, vyplníte formulář, zařízení se restartuje a začne fungovat. Postup:

### 1. Nainstalujte si aplikaci ntfy.sh

Najdete pod názvem **ntfy** (autor Philipp Heckel) v:
- 📱 **Google Play** (Android): https://play.google.com/store/apps/details?id=io.heckel.ntfy
- 🍎 **App Store** (iOS): https://apps.apple.com/app/ntfy/id1625396347

Aplikace je zdarma, **bez registrace**, bez reklam. Stačí ji nainstalovat, pak ji použijete v kroku 6.

### 2. Zapněte zařízení

Pokud má spínač, zapněte ho. Pokud má baterii s konektorem, připojte.

Po zapnutí by se měla **LED dioda (skrze průzor ve víku) začít rozblikávat modře** — trojitý blik každé 3 s. To je **konfigurační režim** — zařízení čeká na konfiguraci (10 minut, pak usne a zkusí znovu při dalším probuzení).

> Pokud LED svítí modře pevně 5–10 s a pak zhasne / přeblikne na zelenou nebo červenou, zařízení **už je nakonfigurované** z dřívějška. Pokud chcete přenastavit, viz sekce „Resetování konfigurace" níže.

### 3. Připojte telefon na WiFi zařízení

V telefonu otevřete WiFi nastavení. V seznamu sítí najděte **„garaz-XXXXXX"** (kde XXXXXX je 6 hex znaků unikátní pro vaše zařízení — např. `garaz-235CE8`).

Síť je **otevřená, bez hesla**. Klepněte na ni a připojte se. Telefon může vypsat varování „Tato síť nemá přístup k internetu" — to je v pořádku, my chceme jen otevřít konfigurační stránku.

### 4. Otevřete konfigurační stránku

V prohlížeči zadejte adresu:

```
http://192.168.4.1
```

Měl by se zobrazit formulář **„Hlídač vrat — konfigurace"**.

### 5. Vyplňte formulář

| Pole | Co tam napsat |
|---|---|
| **WiFi síť (SSID)** | Vyberte ze seznamu vaši domácí WiFi. (Pokud chybí, znovu načtěte stránku — zařízení nascanovalo sítě.) |
| **Heslo WiFi** | Heslo k vaší domácí WiFi. |
| **ntfy.sh topic** | Předvyplněný náhodný kód, např. `garaz-48F6EE-235CE8`. ⚠️ **Tento kód si zapamatujte / opište** — budete ho potřebovat v kroku 6. Můžete ho nechat předvyplněný, nebo nahradit vlastním (10+ znaků, ne slovník — topic je veřejný, kdokoli kdo ho zná, vidí vaše notifikace). |
| **Název zařízení** | Libovolné, např. „garaz" nebo „domeček". Pro vaši orientaci, kdybyste měli víc zařízení. |
| **Začátek nočního okna** | Hodina kdy začnou alerty. Default `22`. |
| **Konec nočního okna** | Hodina kdy alerty skončí. Default `6`. |
| **Hodina denní kontroly** | Kdy přijde heartbeat „žiju" (jednou denně). Default `21`. |
| **Interval kontroly** | Jak často zařízení měří náklon. Default `300` (5 min). |

Klepněte **„Uložit a otestovat WiFi"**.

Zařízení teď zkusí připojit se k vaší WiFi (~15 s). Pokud heslo nesedí, dostanete chybu a můžete zkusit znovu. Pokud OK, zobrazí se „✅ Uloženo" a zařízení se samo restartuje.

### 6. Subscribe v aplikaci ntfy.sh

Po restartu telefonu (cca 10 s) se telefon sám odpojí od „garaz-XXXXXX" (síť přestane existovat). Připojte ho zpět na vaši **domácí WiFi**.

V aplikaci **ntfy**:
1. Klepněte na **+** vpravo dole (přidat subscription)
2. Do pole **„Topic name"** vložte topic z kroku 5 (např. `garaz-48F6EE-235CE8`)
3. **„Server"** nechte na `ntfy.sh` (default)
4. Klepněte **„Subscribe"**

### 7. Ověření že to funguje

Po restartu (kroku 5) by mělo zařízení během cca 10 sekund:
- 🟢 **Zelená LED svítí 5 s** (pokud vše OK) → poslalo se „Hlidac garazovych vrat aktivni"
- 🔴 **Červená LED svítí 5 s** (pokud něco selhalo) → zkontrolujte hesla/topic, opakujte krok 5

Současně by vám měla **dorazit notifikace „Hlidac garazovych vrat aktivni"** v ntfy.sh aplikaci. Otevřete ji a uvidíte stav baterie, signál a aktuální orientaci.

**Pokud notifikace nedorazila** ani po 30 s a LED svítí zeleně:
- Zkontrolujte, že je topic v aplikaci ntfy přesně stejný jako ten ve formuláři (case-sensitive!)
- Zkontrolujte že telefon je na WiFi (pokud na mobilních datech, taky funguje)

### 8. Test detekce náklonu (volitelné, doporučené)

Než zařízení namontujete na vrata, otestujte si že detekce funguje. Buď:
- **Reálný test (počká do noci):** namontujte, otevřete vrata po 22:00 (nebo dle nastavení) — měl by přijít alert.
- **Rychlý test (hned):** přes konfiguraci nastavte „Začátek nočního okna" na aktuální hodinu, pak nakloňte zařízení o 90° (na bok). Při příští kontrole (do ~5 min, podle intervalu) dorazí alert „GARAZ OTEVRENA!". Vraťte zařízení do původní polohy a okno alertu vraťte na 22.

### Resetování konfigurace

Pokud chcete změnit nastavení (jiná WiFi, jiný topic) nebo zařízení znovu nakonfigurovat:

1. **Vypněte zařízení** spínačem.
2. **Propojte piny RX a TX** na headeru (na silku označené `RX` a `TX`, případně `GPIO20` a `GPIO21` — jsou to dva sousední piny, dají se zkratovat 2-pin jumperem nebo kouskem drátu).
3. **Zapněte zařízení.**
4. LED začne **modře blikat trojitě** = AP režim aktivní. Pokračujte krokem 3 výše.

Po nakonfigurování spínač vypněte, jumper odeberte (jinak se AP režim spustí znovu při dalším zapnutí), spínač zapněte → normální provoz.

---

## Jaké notifikace budete dostávat

Existují **4 druhy** zpráv, podle situace:

### 🚀 „Hlidac garazovych vrat aktivni" — po zapnutí

Pošle se jednou, hned po tom co zařízení nastartuje (zapnutí spínače, výměna baterie, první instalace).

**Co v ní stojí:**
```
Čas: 17:23:45
Baterie: 95 % (4,18 V)
Signál: ▮▮▮▮▮ (-54 dBm)

Reference zavřených vrat zachycena.
Orientace: leží naplocho (Z dominantní) (3° od horizontály).

Pokud orientace neodpovídá realitě (vrata mají být zavřená při instalaci),
při zavřených vratech zařízení vypnout a zapnout — uloží se nová reference.
```

**Co to znamená:**
- Zařízení se nastartovalo, čas se synchronizoval, baterie nabitá, WiFi v pohodě
- „Reference zachycena" = senzor si zapamatoval aktuální polohu vrat jako „zavřeno"
- Pokud orientace v zprávě neodpovídá skutečné poloze zavřených vrat (např. píše „leží naplocho" ale vrata jsou vlastně otevřená), zařízení v zavřené poloze **vypnout a znovu zapnout** spínačem — uloží se nová reference
- Pokud tahle zpráva nepřišla, něco selhalo — projděte sekci „Co dělat když..."

### 🚨 „GARAZ OTEVRENA!" — urgentní v noci

Jediná zpráva která má **urgent** prioritu (na iPhone i Androidu obejde tichý režim, rozsvítí displej).

**Kdy přijde:**
- Mezi 22:00 a 06:00 (nebo dle nastavení)
- Vrata jsou otevřená (náklon > 60° od původní polohy)
- **Při každé kontrole** (cca každých 5 min, dokud vrata nezavřete) — chceme abyste byli upozorněni opakovaně, ne jednou a dost

**Co v ní stojí:**
```
Čas: 22:30
Náklon: 67° (limit 60°)
Baterie: 85 %

Zkontroluj vrata.
```

**Co dělat:** zkontrolujte garáž. Buď fyzicky, nebo přes kameru / sousedy.

> Pokud zařízení ztratilo synchronizaci času (např. WiFi výpadek delší dobu), místo času v notifikaci uvidíte `Čas: (čas neznámý)`. Alert přesto pošle — bezpečnostní funkce funguje i bez přesného času.

### ✅ „Garaz - denni kontrola" — denní heartbeat

Posílá se **jednou denně, od 21:00**. Pokud bylo zařízení ve 21:00 zaneprázdněné (poslední alert, WiFi sync), dorazí o pár minut později. Nikdy ne dříve.

**Smysl:** ověření že zařízení žije a senzor funguje. **Pokud ji jeden den nedostanete, něco se pokazilo** — vybitá baterie, mrtvý ESP, vypnutá WiFi.

**Co v ní stojí:**
```
Čas: 21:00
Stav: ZAVŘENO
Náklon: 2°
Baterie: 87 % (4,10 V)
Signál: ▮▮▮▮▯ (-67 dBm)
Běží: 47d 3h 12m

Pokud tato denní kontrola někdy nedorazí, něco se pokazilo — zkontroluj zařízení.
```

### ⚠️ „Hlidac vrat - CHYBA" — diagnostické chyby

Pošle se když zařízení detekuje problém — typicky **senzor přestal odpovídat**. Priority `high` (důraznější než heartbeat, ale ne urgent).

**Kdy přijde:**
- Senzor nereaguje (uvolněný kabel? rozbitý modul?)
- Reference nebyla zachycena po startu (vypnutí/zapnutí proběhlo špatně)
- WiFi výpadek 3× po sobě (zařízení bylo offline) — pošle se na prvním reconnectu
- Aby vás chyby nezahltily, posílají se nejvýš jednou za **30 minut**

**Co v ní stojí:**
```
Čas: 14:23
Počet chyb od posledního hlášení: 3
Poslední: Senzor nereaguje (probuzení selhalo po 3 pokusech)
Baterie: 87 %
Signál: ▮▮▮▮▯ (-67 dBm)

Chyby se opakují — pravděpodobně skutečný problém.
Zkontroluj připojení senzoru (4 vodiče), případně vyměň modul.
```

**Co dělat:** otevřete krabičku (vyšroubujte 4 šroubky ve víku), zkontrolujte:

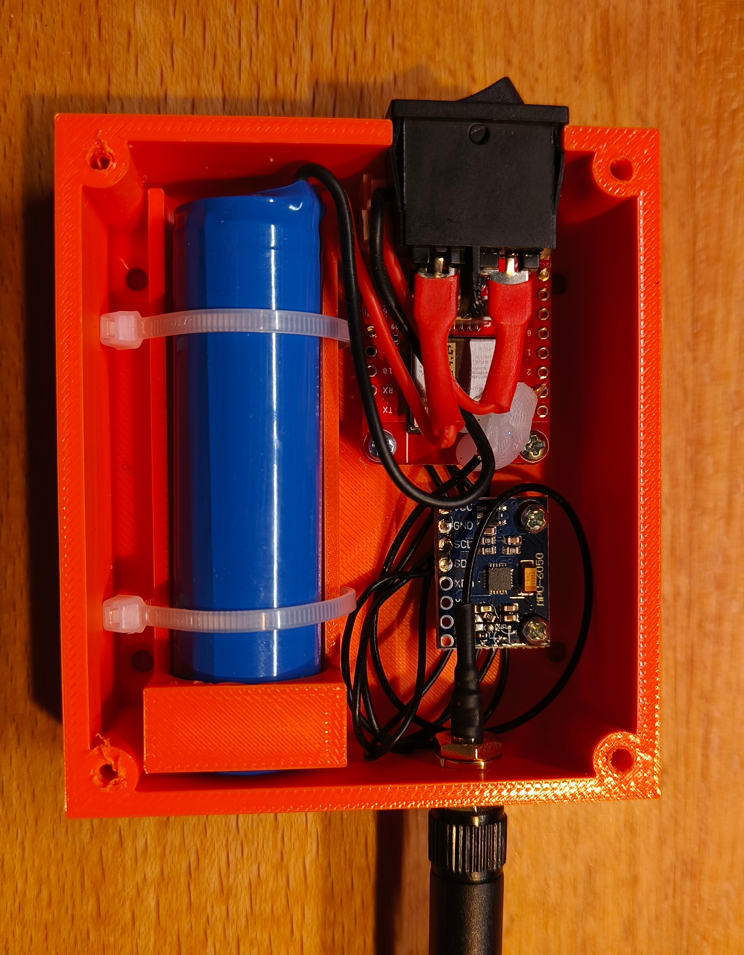
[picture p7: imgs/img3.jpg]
Vnitřek krabičky — referenční obrázek co kde má být


- Jsou všechny 4 vodiče k senzoru (GY-521, vpravo nahoře na obrázku) zapojené (VCC, GND, SDA, SCL)? Pájené spoje by se neměly uvolnit.
- Není kabel přerušený?
- **Vypněte a zapněte** zařízení spínačem (vlevo na obrázku) — pokud problém zmizí, byl to dočasný glitch
- Pokud chyby pokračují, senzor je pravděpodobně mrtvý → výměna modulu

**Důležité:** pokud chodí chyby, **alerty na otevřená vrata nemusí fungovat**. Zařízení nedokáže měřit náklon, takže by nevidělo ani skutečně otevřená vrata. **Berte chybové zprávy vážně.**

---

## LED na zařízení

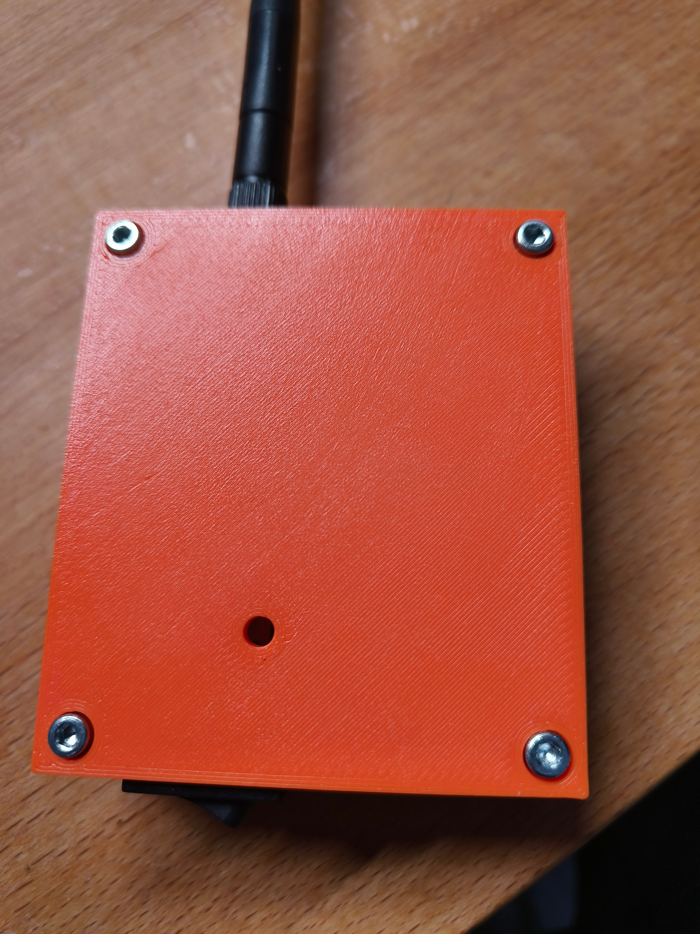
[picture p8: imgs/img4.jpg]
Víko krabičky s průzorem pro LED diodu uprostřed


V krabičce je viditelná RGB LED dioda (skrz **průzor ve víku** — viditelná na fotce výše, malá kulatá dírka uprostřed). Slouží jako sekundární indikátor stavu — víc se na ni ale spoléhat nemá smysl, primární kanál jsou notifikace v telefonu.

| Barva | Význam |
|---|---|
| 🔵 **Modrá svítí** | Cold boot právě probíhá (po zapnutí spínače / výměně baterie). Trvá 5–10 s. |
| 🔵 **Modrá — trojitý blik každé 3 s** | **Konfigurační režim (AP)**. Zařízení vystavilo WiFi „garaz-XXXXXX" a čeká, až se na něj připojíte telefonem a vyplníte formulář. Nastane při prvním zapnutí (prázdná konfigurace) nebo když propojíte piny RX+TX (GPIO20+GPIO21). Trvá až 10 min, pak usne a zkusí znovu při dalším probuzení. Viz [První nastavení](#první-nastavení-instalace) výše. |
| 🟢 **Zelená 5 s svítí + 10 s bliká** | Cold boot proběhl úspěšně. Reference zachycena, WiFi OK, notifikace odeslána. Bliká během 10s okna pro nahrávání nového firmware (technické). |
| 🔴 **Červená 5 s svítí + 10 s bliká** | Cold boot selhal — typicky chybí WiFi, nepodařilo se zachytit referenci nebo senzor nereaguje. Měla by dorazit i CHYBA notifikace (pokud WiFi zafungovala). |
| 🟣 **Fialová svítí 5 s** | Právě byl odeslán alert „GARÁŽ OTEVŘENA". Vidíte jenom během běžné kontroly (každých 5 min), kdy byl alert úspěšně doručen. |
| 🔴 **Červená svítí 5 s** během běžného provozu | Některá kontrola selhala (senzor nereaguje nebo se nepodařilo poslat zprávu). Chybová notifikace dorazí po reconnectu WiFi. |
| **Zhasnutá** | Normální stav během deep sleep i během kontroly co neměla nic na hlášení. Většinu času uvidíte zhasnutou — to je správně. |

**Proč to tak svítí krátce:** dlouhé svícení by žralo baterii. 5 s solid umožňuje zaregistrovat barvu zrakem během krátké návštěvy garáže, deep sleep pak LED úplně odpojí (0 µA).

---

## Jak rozumět údajům ve zprávách

### Baterie v procentech

| % | Voltáž | Stav | Co dělat |
|---|---|---|---|
| **>90** | >4,1 V | Plně nabito | nic |
| **70–90** | 3,9–4,1 V | Vysoký stav | nic |
| **40–70** | 3,8–3,9 V | Normální | nic |
| **20–40** | 3,7–3,8 V | Začíná docházet | naplánovat nabití do týdne |
| **5–20** | 3,5–3,7 V | Nízká | **brzy nabít** |
| **<5** | <3,5 V | Kritická | **nabít HNED**, jinak hrozí výpadek |
| **0** | ≤3,2 V | Vybitá | zařízení vypnuto, nezachycuje |

Procenta jsou orientační (LiPo baterie má nelineární vybíjení), ale dávají dobrý odhad. **Důvěřujte heartbeatu — pokud chodí, zařízení žije.**

### Síla signálu (RSSI)

V zprávě vidíte signál jako 5-segmentový bar (`▮▮▮▮▮` plný / `▮▯▯▯▯` jeden) + dBm hodnotu:

| Bar | dBm | Co to znamená |
|---|---|---|
| **▮▮▮▮▮** | > −60 | velmi blízko routeru, žádný problém |
| **▮▮▮▮▯** | −60 až −70 | normální, plně dostačuje |
| **▮▮▮▯▯** | −70 až −80 | slabší, ale ještě funguje |
| **▮▮▯▯▯** | −80 až −90 | hraniční, občas může vypadnout |
| **▮▯▯▯▯** | < −90 | nestabilní, alerty se nemusí dostat |

Pokud se zhorší, můžete zvážit lepší pozici routeru nebo WiFi extender. Ale obvykle není třeba řešit.

### Náklon ve stupních

`Naklon: X°` — o kolik se vrata pohnula od původní polohy (zachycené při startu).

- **0–10°** = zavřeno (drobné chvění z větru, vibrací)
- **10–60°** = pootevřeno (normálně by se to nemělo stávat, ale není to alert)
- **>60°** = otevřeno (alert v noci!)

### Čas ve zprávách

Čas v notifikacích (`Čas: HH:MM`) **nemusí vždy přesně odpovídat skutečnému času** — může být odchýlený o pár minut. Zařízení nemá hodinový krystal pro přesné měření času; používá interní oscilátor, který drifuje (typicky ~1 s za hodinu = ~24 s za den). Synchronizace přes internet:

- **Vynucená**: minimálně jednou za 24 h
- **Příležitostná**: kdykoli zařízení připojí WiFi z jiného důvodu (alert, heartbeat, chybové hlášení) a od posledního syncu uplynulo ≥ 10 min — sync proběhne při té příležitosti zdarma

V typický den se sync provede aspoň při heartbeatu (21:00), takže drift mezi syncy nepřesáhne ~30 s. Pro účely hlídání nočního okna 22:00–06:00 (nebo dle nastavení) je to dostatečně přesné, drobné odchýlky neovlivňují funkci.

Pokud zařízení ztratilo synchronizaci úplně (např. dlouhý WiFi výpadek, čerstvý cold boot bez internetu), v zprávě uvidíte `Čas: (čas neznámý)`. Alerty fungují i tak — jenom bez timestampu.

---

## Co dělat když...

### V noci přijde urgentní notifikace

1. **Zkontrolujte vrata** — fyzicky, kamerou, požádejte souseda
2. Pokud je to **planý poplach** (např. silný vítr roztřásl vrata):
   - Žádná akce není nutná, zařízení samo zase zaregistruje „zavřeno" jakmile se náklon vrátí
   - Pokud vítr nadále působí, dostanete další alert do 5 minut (cyklicky až do uklidnění)
3. Pokud někdo vrata reálně otevřel (zloděj, zapomenuté otevření): jednejte podle situace

### Zpráva „GARAZ OTEVRENA" se opakuje každých 5 min

Vrata jsou pravděpodobně **skutečně otevřená a zaseklá** v té poloze. Buď je někdo zapomněl zavřít, nebo má motor vrat poruchu. Alerty budou chodit dokud vrata nezavřete (nebo dokud nedojde baterie).

### Heartbeat (denní zpráva od 21:00) nepřišel

Možnosti, od nejpravděpodobnější:
1. **Vybitá baterie** — ESP nemá energii na WiFi
2. **WiFi výpadek** — router restartoval, ESP se zatím nepřipojilo (po reconnectu by měla dorazit chybová notifikace „WiFi nedostupné Xx po sobě")
3. **Spadlý ntfy.sh** (vzácné, ale stane se)
4. **Hardware selhal** — ESP nebo senzor vypovědělo službu

**Co udělat:** počkejte do dalšího dne. Pokud druhý den znova nepřišel, otevřete krabičku a zkontrolujte:
- Svítí na zařízení LED? Pokud bliká **červeně**, je v chybovém stavu (viz LED sekce výše)
- Je baterie nabitá? (zkuste nabít přes USB-C kabel — viz Nabíjení)
- Jsou všechny vodiče k senzoru zapojené?

### Nepřišla úvodní zpráva po zapnutí

Pravděpodobně se nepodařilo připojit k WiFi nebo nesynchronizovat čas. Zařízení po 5 minutách znovu zkusí. Sledujte LED:
- **Zelená blikající** ~10 s po zapnutí = vše OK, jen se nepovedlo poslat (síťový problém)
- **Červená blikající** ~10 s po zapnutí = chyba (WiFi nedostupná, senzor nereaguje, čas nesynchronizován)

Pokud po 30 min nic nedoraziilo:
- WiFi router běží? Heslo / SSID správné?
- Pokud LED neukazuje žádnou aktivitu = vybitá baterie nebo HW selhání

### Baterie pod 20 %

Naplánujte nabití do týdne. Při kritickém stavu (<5 %) se zařízení samo vypne kolem 3,2 V — nehrozí poškození baterie.

---

## Nabíjení

Zařízení má **vestavěný USB-C konektor + nabíjecí čip**. Nabíjení:

1. ⚠️ **Spínač musí být v poloze ON** — pokud je vypnutý, baterie je fyzicky odpojená a nabíjet se nebude. (Spínač zapnete → zařízení normálně běží i během nabíjení.)
2. Připojte USB-C kabel do zařízení
3. Druhý konec do jakéhokoliv USB nabíječe (telefonní nabíječka, powerbanka, PC, …)
4. Indikační LED na desce nabíjení svítí během nabíjení (na samotném ESP modulu, mimo průzor)
5. Zhasne když je baterie plně nabitá (~2–3 hodiny pro 1000 mAh, ~6 h pro 18650)
6. Zařízení **může běžet i během nabíjení**, není třeba vypínat

**Důležité:** zařízení se po vypnutí/zapnutí spínačem (nebo výměně baterie) chová jako po prvním zapnutí — pošle „Hlidac garazovych vrat aktivni" notifikaci a znovu zachytí referenci polohy vrat.

➜ **Nabíjení samotné** s běžícím zařízením tohle nevyvolá (napájení nepřerušuje). Pokud ale potřebujete novou referenci (vrata se posunula, vyměnili jste senzor), **vypněte a zapněte spínač při zavřených vratech**.

---

## Časté otázky

**Q: Co když dorazí FALSE positive (alert, ale vrata zavřená)?**
A: Vyhodnoťte jednou. Pokud se opakuje, zařízení může mít posunutou referenci (např. vrata si „sednou" za pár měsíců). Při zavřených vratech **vypněte a zapněte spínač** — zařízení zachytí novou referenci z aktuální polohy.

**Q: Funguje to bez WiFi?**
A: Ne. Zařízení potřebuje WiFi pro odeslání notifikace přes ntfy.sh. Bez WiFi neudělá nic užitečného (žádný lokální alert / siréna).

**Q: Jak nastavit, která vrata má zařízení hlídat?**
A: Senzor musí být **pevně přilepený k vratům** (ne na rámu, ne na pohyblivé části okolo). Při zapnutí spínače se zachytí aktuální poloha jako „zavřeno". Pak když se vrata pohnou >60°, alert.

**Q: Funguje to na sekční / rolovací / křídlová vrata?**
A: Ano, na všechna, která se naklánějí o víc než 60° při otevření. Sekční (skládací do stropu) typicky 90°, křídlová 90°, rolovací (svisle navíjená) jen ~5–10° — **na rolovací nefunguje**, je třeba jiný senzor.

**Q: Lze zařízení rozšířit o detekci přes den?**
A: Aktuálně hlídá jen 22:00–06:00 (nebo dle nastavení v konfiguraci). Rozšíření na 24/7 by šlo, ale baterie vydrží míň (víc alertů = víc WiFi = víc energie). Pokud potřeba, dá se firmware upravit.

**Q: Co když chci notifikaci vypnout (např. legitimně otevírám vrata v noci)?**
A: Buď vypněte ntfy.sh appku v telefonu před tím, nebo akceptujte alert (přijde každých ~5 min dokud vrata nezavřete). Plánovaný „suppress" mód není.

---

## Technický overview pro zvědavé

Zařízení obsahuje:
- **ESP32-C3** mikrokontroler (LaskaKit C3-LPKit v4) — mozek, WiFi, USB-C
- **MPU6050 / MPU6500** akcelerometr (GY-521 modul) — měří náklon
- **WS2812 NeoPixel** RGB LED — indikace stavu
- **LiPo baterii** s integrovaným nabíjecím čipem na desce
- **Spínač** v sérii s baterií (pro vynucenou novou referenci)

Cyklus:
1. ESP32 spí 99,9 % času (deep sleep, naměřeno **19 µA**)
2. Každých 5 minut se na ~5 s probudí
3. Probudí senzor přes I²C, změří náklon (3 retry pokusy proti glitchům)
4. Pokud je důvod (alert, denní heartbeat, sync času, error report), zapne WiFi a pošle zprávu
5. Zpět do spánku

**Životnost na baterii** (18650 3200 mAh, klidový provoz bez alertů): teoreticky ~1,5–2 roky. Reálně limitované samovybíjením baterie a chladem v zimní garáži → **plánovat nabíjení 1× ročně**.

Detaily v `README.md`.

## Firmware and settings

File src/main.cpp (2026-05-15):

// Garage door notif — orchestrace pro LaskaKit ESP32-C3-LPKit v4.
//
// Architektura:
//   COLD BOOT (power-on / RTC mem cleared):
//     1. modra LED, WiFi connect + NTP sync
//     2. MPU bring-up + baseline capture (50 vzorku, prumer)
//     3. Boot notifikace na ntfy.sh
//     4. zelena/cervena LED solid + blink (upload window)
//     5. PERIPH_EN LOW, deep sleep WAKE_INTERVAL_S
//
//   WAKE (z deep sleep):
//     1. MPU wake + measure (3 retry pri I2C glitchi)
//     2. Tilt vs baseline + hystereze: open >60°, close <40°
//     3. Casova logika rozhodne co posilat (alert / heartbeat / NTP / errors)
//        - Alert fail-open: kdyz cas neni synced, presto posli (security feature)
//        - Heartbeat year-safe: kontrola pres unix elapsed, ne yday
//     4. WiFi connect → ntp_sync (opportunistic) → poslat
//     5. fialova LED 5 s pri alertu, cervena 5 s pri chybe
//     6. PERIPH_EN LOW, deep sleep
//
// Modulova struktura — viz hlavicky v include/.

#include <Arduino.h>
#include "esp_sleep.h"
#include "esp_system.h"
#include "soc/rtc.h"
extern "C" uint64_t rtc_time_slowclk_to_us(uint64_t rtc_cycles, uint32_t period);
extern "C" uint64_t rtc_time_get();
extern "C" uint32_t rtc_clk_slow_freq_get_hz();

#include "ap_config.h"
#include "config.h"
#include "led.h"
#include "net.h"
#include "notifications.h"
#include "power.h"
#include "sensor.h"
#include "state.h"
#include "storage.h"
#include "time_utils.h"

namespace {

// Heartbeat dedup pres last_heartbeat_unix — year-safe (yday-pristup mel
// kolizi na Jan 1 / Dec 31). 23 h misto 24 h dava margin proti drobnemu
// driftu mezi wakes.
constexpr uint64_t HEARTBEAT_MIN_GAP_S = 23 * 3600;

bool mpu_bringup() {
  mpu_initialize_i2c(SDA_PIN, SCL_PIN);
  if (!mpu_wake()) return false;
  uint8_t who = mpu_who_am_i();
  state.mpu_who_id = who;
  Serial.printf("[mpu] WHO_AM_I=0x%02X (%s)\n", who, mpu_chip_name(who));
  return mpu_is_known_chip(who);
}

void enter_deep_sleep() {
  Serial.printf("[sleep] %sgoing to sleep for %lu s\n",
                DEEP_SLEEP_ENABLED ? "" : "[DEBUG simulated] ",
                static_cast<unsigned long>(cfg.wake_interval_s));
  Serial.flush();

  if (DEEP_SLEEP_ENABLED) {
    periph_power_off_for_sleep();
    esp_sleep_enable_timer_wakeup(static_cast<uint64_t>(cfg.wake_interval_s) * 1000000ULL);
    esp_deep_sleep_start();
    // unreachable — wake = reset
  }
  // Debug mode: vrati se do volajiciho. setup() pak preda rizeni loop()u,
  // ktery simuluje wake po delay. Perif rail zustava HIGH (NeoPixel + MPU
  // napajene), USB-CDC nikdy neodpadne, vsechny logy zachyceny v monitoru.
}

void do_cold_boot() {
  Serial.println(F("=== COLD BOOT ==="));
  // Preserve double-RST tracking (nastaveno v setup() pred volanim).
  uint64_t save_rtc_us = state.last_cold_boot_rtc_us;
  uint8_t  save_rapid  = state.rapid_reset_count;
  state = AppState{};                 // zero-init vsech ostatnich fieldu
  state.last_cold_boot_rtc_us  = save_rtc_us;
  state.rapid_reset_count      = save_rapid;
  state.magic                  = STATE_MAGIC;
  state.boot_count             = 1;

  led_show(0, 0, 60);   // modra = cold boot bezi

  bool online = wifi_connect();
  if (online) {
    ntp_sync();
    state.wifi_consecutive_fails = 0;
  } else {
    state.wifi_consecutive_fails++;
  }

  if (!mpu_bringup()) {
    Serial.println(F("[fatal] sensor not responding"));
    queue_error("Senzor nereaguje (možný uvolněný kabel)");
  } else {
    Vec3 base;
    if (mpu_measure_avg(50, base)) {
      state.baseline       = base;
      state.baseline_valid = true;
      Serial.printf("[mpu] baseline ax=%+.3f ay=%+.3f az=%+.3f |a|=%.3f g\n",
                    base.x, base.y, base.z, vec_mag(base));
    } else {
      Serial.println(F("[mpu] baseline measure FAIL"));
      queue_error("Měření reference selhalo (senzor nereaguje stabilně)");
    }
    mpu_sleep();
  }

  if (online) {
    float vbat = read_vbat();
    float pct  = vbat_to_percent(vbat);
    int   rssi = wifi_rssi();
    if (state.baseline_valid) {
      send_boot_notification(vbat, pct, rssi, state.baseline);
    }
    flush_pending_errors(pct, rssi);
    wifi_disconnect();
  }

  bool boot_ok = online && state.baseline_valid && state.pending_error_count == 0;
  uint8_t r_ind = boot_ok ? 0  : 80;
  uint8_t g_ind = boot_ok ? 80 : 0;
  uint8_t b_ind = 0;

  led_show(r_ind, g_ind, b_ind);
  delay(LED_INDICATION_MS);

  Serial.printf("[boot] %lu s upload window — spust ted `pio run -t upload`\n",
                static_cast<unsigned long>(COLD_BOOT_UPLOAD_WINDOW_S));
  for (uint32_t s = 0; s < COLD_BOOT_UPLOAD_WINDOW_S; s++) {
    led_show(r_ind, g_ind, b_ind);
    delay(LED_BLINK_HALF_PERIOD_MS);
    led_off();
    delay(LED_BLINK_HALF_PERIOD_MS);
  }
  led_off();
}

// Pokus o MPU mereni s retry. Vraci true pri uspechu; zaradi chybu do queue
// pri opakovanem selhani. Kazda iterace: wake → measure. Pokud wake nikdy
// neprosel → "nereaguje"; pokud wake prosel ale measure ne → "měření selhalo".
bool measure_with_retry(Vec3& a) {
  bool wake_ever_ok = false;
  for (uint8_t attempt = 1; attempt <= MPU_RETRY_COUNT; attempt++) {
    if (mpu_wake()) {
      wake_ever_ok = true;
      if (mpu_measure_avg(6, a)) {
        if (attempt > 1) Serial.printf("[mpu] OK po %u. pokusu\n", attempt);
        mpu_sleep();
        return true;
      }
    }
    if (attempt < MPU_RETRY_COUNT) {
      Serial.printf("[mpu] retry %u/%u (wake_ok=%d)\n",
                    attempt, MPU_RETRY_COUNT - 1, static_cast<int>(wake_ever_ok));
      delay(MPU_RETRY_DELAY_MS);
    }
  }
  if (wake_ever_ok) {
    mpu_sleep();
    queue_error("Měření selhalo (3 pokusy bez čitelné odpovědi)");
  } else {
    queue_error("Senzor nereaguje (probuzení selhalo po 3 pokusech)");
  }
  return false;
}

// Snapshot rozhodnuti co potrebujeme online. Pocita se za behu wake cyklu na
// zaklade aktualniho stavu door/tilt/cas/error queue.
struct WakeActions {
  bool alert         = false;
  bool heartbeat     = false;
  bool ntp_resync    = false;
  bool error_report  = false;
  bool time_synced   = false;     // doplneno, abychom alert mohli mit "(cas neznamy)" label
};

WakeActions compute_wake_actions(bool measure_ok, bool door_open) {
  WakeActions act;
  act.time_synced = time_is_synced();
  time_t now = 0;
  if (act.time_synced) time(&now);

  // Alert: kdyz dvere otevrene + (nocni okno NEBO cas neni synced fail-open).
  // Fail-open zaruci, ze pri NTP outage user nezustane slepe k vykradeni.
  if (measure_ok && door_open) {
    bool in_alert_window = act.time_synced ? is_night_window() : true;
    if (in_alert_window) {
      if (elapsed_at_least(static_cast<uint64_t>(now), state.last_alert_unix, ALERT_RATE_LIMIT_S)) {
        act.alert = true;
      } else {
        int64_t since = static_cast<int64_t>(now) - static_cast<int64_t>(state.last_alert_unix);
        Serial.printf("[rate] alert suppressed (last %lld s ago)\n", static_cast<long long>(since));
      }
    }
  }

  // Heartbeat: jen kdyz mame cas. >= HEARTBEAT_HOUR misto == zachyti zmeskane
  // wakes. Year-safe dedup pres unix elapsed >= 23h.
  if (act.time_synced && current_hour() >= cfg.heartbeat_hour &&
      elapsed_at_least(static_cast<uint64_t>(now), state.last_heartbeat_unix, HEARTBEAT_MIN_GAP_S)) {
    act.heartbeat = true;
  }

  if (!act.time_synced) {
    act.ntp_resync = true;
  } else if (elapsed_at_least(static_cast<uint64_t>(now), state.last_ntp_unix, NTP_RESYNC_INTERVAL_S)) {
    act.ntp_resync = true;
  }

  if (state.pending_error_count > 0) {
    if (!act.time_synced) {
      act.error_report = (act.alert || act.heartbeat || act.ntp_resync);
    } else if (elapsed_at_least(static_cast<uint64_t>(now), state.last_error_report_unix, ERROR_REPORT_RATE_LIMIT_S)) {
      act.error_report = true;
    }
  }
  return act;
}

void do_wake_cycle() {
  state.boot_count++;
  Serial.printf("=== WAKE #%u ===\n", state.boot_count);

  // 1. MPU mereni
  Vec3 a{};
  bool measure_ok = false;

  if (!state.baseline_valid) {
    Serial.println(F("[warn] baseline not set — vypnout a zapnout pri zavrenych vratech"));
    queue_error("Reference není zachycena (vypnout a zapnout při zavřených vratech)");
  } else {
    mpu_initialize_i2c(SDA_PIN, SCL_PIN);
    measure_ok = measure_with_retry(a);
  }

  // 2. Tilt + hystereze
  float tilt = 0.0f;
  bool  door_open = state.door_was_open;
  if (measure_ok) {
    tilt = angle_deg(a, state.baseline);
    Serial.printf("[mpu] tilt=%.2f° (baseline mag=%.3f, sample mag=%.3f)\n",
                  tilt, vec_mag(state.baseline), vec_mag(a));
    door_open = state.door_was_open
      ? (tilt > TILT_THRESHOLD_CLOSE)
      : (tilt > TILT_THRESHOLD_OPEN);
    state.door_was_open = door_open;
  }

  // 3. Rozhodnuti
  WakeActions act = compute_wake_actions(measure_ok, door_open);

  if (act.time_synced) {
    char timestr[32];
    format_time(timestr, sizeof(timestr), "%H:%M:%S");
    Serial.printf("[time] %s, hour=%d, night_window(%d-%d)=%s\n",
                  timestr, current_hour(),
                  cfg.night_start_hour, cfg.night_end_hour,
                  is_night_window() ? "YES" : "NO");
  } else {
    Serial.println(F("[time] not synced — alert je fail-open"));
  }

  Serial.printf("[state] door=%s tilt=%.1f° alert=%d heart=%d ntp=%d err=%d (pending=%u, wifi_fails=%u)\n",
                door_open ? "OPEN" : "closed", tilt,
                act.alert, act.heartbeat, act.ntp_resync, act.error_report,
                state.pending_error_count, state.wifi_consecutive_fails);

  // 4. WiFi + posli vse
  bool any_send_ok = false;
  bool any_send_attempted = false;

  if (act.alert || act.heartbeat || act.ntp_resync || act.error_report) {
    if (wifi_connect()) {
      state.wifi_consecutive_fails = 0;
      time_t now_unix; time(&now_unix);
      bool ntp_stale = !time_is_synced() ||
                       elapsed_at_least(static_cast<uint64_t>(now_unix), state.last_ntp_unix,
                                        NTP_OPPORTUNISTIC_INTERVAL_S);
      if (ntp_stale) {
        ntp_sync();
      }

      float vbat = read_vbat();
      float pct  = vbat_to_percent(vbat);
      int   rssi = wifi_rssi();

      if (act.alert) {
        any_send_attempted = true;
        if (send_urgent_alert(tilt, pct, act.time_synced)) {
          any_send_ok = true;
          time_t n; time(&n); state.last_alert_unix = n;
        }
      }
      if (act.heartbeat) {
        any_send_attempted = true;
        if (send_heartbeat(door_open, tilt, vbat, pct, rssi)) {
          any_send_ok = true;
          time_t n; time(&n); state.last_heartbeat_unix = n;
        }
      }
      if (act.error_report) {
        any_send_attempted = true;
        uint32_t before = state.pending_error_count;
        flush_pending_errors(pct, rssi);
        if (state.pending_error_count < before) any_send_ok = true;
      }
      wifi_disconnect();
    } else {
      Serial.println(F("[wifi] connect fail — vse skipnuto, errors zustavaji v queue"));
      state.wifi_consecutive_fails++;
      any_send_attempted = true;
      // Visible reporting: po N po sobe failnutych connect attemptu zarad
      // do queue, aby uzivatel po reconnectu uvidel "byl jsi offline".
      // Queue jen jednou na threshold — counter sice roste dal, ale msg
      // se zaktualizuje s aktualnim poctem.
      if (state.wifi_consecutive_fails >= WIFI_FAIL_REPORT_THRESHOLD) {
        char msg[80];
        snprintf(msg, sizeof(msg),
                 "WiFi nedostupné %u× po sobě — zařízení bylo offline",
                 state.wifi_consecutive_fails);
        queue_error(msg);
      }
    }
  }

  // 5. LED
  bool wake_error = (state.pending_error_count > 0)
                 || (any_send_attempted && !any_send_ok);
  if (act.alert && any_send_ok) {
    led_show(80, 0, 80);   // fialova = alert OK
    delay(LED_INDICATION_MS);
    led_off();
  } else if (wake_error) {
    led_show(80, 0, 0);    // cervena = chyba
    delay(LED_INDICATION_MS);
    led_off();
  }
}

// Brownout / panic detection — pokud RTC mem prezila (state.magic OK), ale
// reset reason je necekany, zaloguj a zarad chybu do queue. Cold boot rutina
// na to nepostouchne.
void check_unexpected_reset() {
  esp_reset_reason_t r = esp_reset_reason();
  const char* label = nullptr;
  switch (r) {
    case ESP_RST_BROWNOUT: label = "Brownout reset (slabá baterie?)"; break;
    case ESP_RST_PANIC:    label = "Firmware panic (exception)"; break;
    case ESP_RST_INT_WDT:  label = "Interrupt watchdog reset"; break;
    case ESP_RST_TASK_WDT: label = "Task watchdog reset"; break;
    default: return;       // POWERON / EXT / SW / DEEPSLEEP — vse OK
  }
  Serial.printf("[boot] necekany reset: %s\n", label);
  queue_error(label);
}

}  // namespace

// Double-RST detection. Counter zije v RTC mem (prezije RST) a inkrementuje
// se pri kazdem ne-timer setupu (= RST nebo true cold boot). Pri deep sleep
// wake se nuluje (stabilni provoz). Pokud counter dosahne DOUBLE_RST_THRESHOLD
// v okne DOUBLE_RST_WINDOW_US, je to user-trigger pro AP mode.
//
// Pri prvnim ever bootu (magic invalid) ma RTC mem nahodny obsah → musime
// fields explicitne inicializovat pred ctenim.
bool detect_double_rst(esp_sleep_wakeup_cause_t cause, bool true_cold_boot) {
  if (true_cold_boot) {
    state.last_cold_boot_rtc_us = 0;
    state.rapid_reset_count = 0;
  }
  if (cause == ESP_SLEEP_WAKEUP_TIMER) {
    state.rapid_reset_count = 0;
    return false;
  }
  // RTC slow clock prezije RST (pouze power-off ho resetuje). Pro mereni gap
  // mezi RST-y vyrobime us z slow clock cycles × period.
  uint64_t now_us = rtc_time_slowclk_to_us(rtc_time_get(), rtc_clk_slow_freq_get_hz());
  uint64_t since  = now_us - state.last_cold_boot_rtc_us;
  if (state.last_cold_boot_rtc_us > 0 && since < DOUBLE_RST_WINDOW_US) {
    state.rapid_reset_count++;
  } else {
    state.rapid_reset_count = 1;
  }
  state.last_cold_boot_rtc_us = now_us;
  Serial.printf("[boot] rapid_reset_count=%u (since=%llu ms)\n",
                state.rapid_reset_count, (unsigned long long)(since / 1000));
  if (state.rapid_reset_count >= DOUBLE_RST_THRESHOLD) {
    state.rapid_reset_count = 0;   // neopakovat AP pri dalsim cold bootu
    return true;
  }
  return false;
}

// External AP trigger: pri propojeni AP_TRIGGER_PIN_IN ↔ AP_TRIGGER_PIN_GND
// pri startu vraci true. Po check uvolni oba piny (INPUT high-Z).
bool detect_external_ap_trigger() {
  pinMode(AP_TRIGGER_PIN_GND, OUTPUT);
  digitalWrite(AP_TRIGGER_PIN_GND, LOW);
  pinMode(AP_TRIGGER_PIN_IN, INPUT_PULLUP);
  delay(5);   // settle pullup vs. driven LOW
  bool triggered = (digitalRead(AP_TRIGGER_PIN_IN) == LOW);
  pinMode(AP_TRIGGER_PIN_GND, INPUT);    // release
  pinMode(AP_TRIGGER_PIN_IN, INPUT);     // release (pullup off)
  return triggered;
}

void setup() {
  periph_power_on();
  led_initialize();
  adc_initialize();

  // External AP trigger check — pred Serial init, rychly. Kontrolujeme jen pri
  // cold bootu / RST, ne pri deep sleep wake — kdyby uzivatel zapomnel propojku
  // odstranit, kazdy wake by skocil do AP a baterii by to vycerpalo.
  esp_sleep_wakeup_cause_t cause_early = esp_sleep_get_wakeup_cause();
  bool ext_ap_trigger = false;
  if (cause_early != ESP_SLEEP_WAKEUP_TIMER) {
    ext_ap_trigger = detect_external_ap_trigger();
  }

  Serial.begin(115200);
  delay(SERIAL_INIT_DELAY_MS);
  Serial.println();

  if (ext_ap_trigger) {
    Serial.println(F("[boot] >>> external AP trigger (GPIO20↔GPIO21 short) <<<"));
  }

  // TZ env var se nepřežije deep sleep — nastavit pri kazdem wake.
  setenv("TZ", TZ_CZ, 1);
  tzset();

  esp_sleep_wakeup_cause_t cause = esp_sleep_get_wakeup_cause();
  bool true_cold_boot = (state.magic != STATE_MAGIC);

  bool double_rst = detect_double_rst(cause, true_cold_boot);

  Serial.printf("[boot] cause=%d cold_boot=%d magic=0x%08X\n",
                static_cast<int>(cause), static_cast<int>(true_cold_boot),
                static_cast<unsigned>(state.magic));

  // Nacti NVS config (defaults z config.h pro nenalezene klice, prazdne stringy
  // pro creds → cfg.configured=false pri fresh installu → AP mode).
  cfg_load();

  bool force_ap = double_rst || ext_ap_trigger;
  if (force_ap) {
    if (double_rst)     Serial.println(F("[boot] DOUBLE-RST trigger"));
    if (ext_ap_trigger) Serial.println(F("[boot] external GPIO trigger"));
    Serial.println(F("[boot] mazu NVS config a startuji AP mode"));
    cfg_clear();
    cfg_load();   // znovu nacti = vse defaults
  }

  if (!cfg.configured) {
    Serial.println(F("[boot] NVS prazdne (nebo smazano) → vstupuji do AP modu"));
    run_ap_mode();
    // run_ap_mode bud restartne (po save) nebo deep-sleep (po timeoutu) —
    // sem se nedostaneme. Return je formalita pro toolchain.
    return;
  }

  Serial.printf("[boot] NVS configured (ssid='%s', topic='%s') → normalni boot\n",
                cfg.wifi_ssid, cfg.ntfy_topic);

  if (true_cold_boot) {
    do_cold_boot();
  } else {
    check_unexpected_reset();
    if (cause != ESP_SLEEP_WAKEUP_TIMER) {
      Serial.printf("[boot] cause=%d, RTC mem valid → continuing as wake\n",
                    static_cast<int>(cause));
    }
    do_wake_cycle();
  }

  enter_deep_sleep();
}

void loop() {
  // V produkci nedosazitelne (deep sleep nevrati). V debug modu
  // (DEEP_SLEEP_ENABLED=false) simulujeme wake cyklus: delay misto sleep,
  // pak do_wake_cycle a opet enter_deep_sleep (ktery se v debug rezimu
  // hned vrati). State preziva vse v RAM, RTC mem netreba.
  if (DEEP_SLEEP_ENABLED) return;

  delay(static_cast<uint32_t>(cfg.wake_interval_s) * 1000UL);
  Serial.println(F("[boot] [DEBUG simulated] woke up"));
  do_wake_cycle();
  enter_deep_sleep();
}

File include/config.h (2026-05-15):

// Centralizovane konstanty pro celou aplikaci.
// HW piny pro LaskaKit ESP32-C3-LPKit v4 + logicke prahy z README.md sekce
// "Architektura". Pri zmene desky nebo behavior tweaks meni se tady.
//
// Citlive credentials (WIFI_SSID, NTFY_TOPIC, ...) jsou v include/secrets.h
// (gitignored).

#pragma once

#include <Arduino.h>

// ===== HW piny =====
constexpr uint8_t  SDA_PIN        = 6;
constexpr uint8_t  SCL_PIN        = 7;
constexpr uint8_t  NEOPIXEL_PIN   = 9;
constexpr uint8_t  PERIPH_EN_PIN  = 4;
constexpr uint8_t  VBAT_ADC_PIN   = 0;
constexpr float    VBAT_DIVIDER   = 1.769f;
constexpr uint8_t  LED_BRIGHTNESS = 60;

// External AP trigger — propojka pri startu = AP mode. Pouziti pri power-off
// uzivateli kterym double-RST nefunguje (power switch = full power cycle,
// RTC mem vymazana, detekce dvou RST za sebou nemozna).
//
// Pouzivame UART0 piny GPIO20 (RX) a GPIO21 (TX) — v app firmwaru nepouzite
// (Serial = USB-CDC), fyzicky sousedi na headeru → standardni 2-pin jumper.
// Pred zapnutim spinacem propoj GPIO20 ↔ GPIO21, zapni → AP mode.
//
// Pozor: pokud pouzivas dual-log USB-UART adapter pri c3power debug, ten je
// na techto pinech. Pred triggerovanim AP rezimu odpoj.
constexpr uint8_t  AP_TRIGGER_PIN_IN  = 20;   // UART0 RX, INPUT_PULLUP — short → AP
constexpr uint8_t  AP_TRIGGER_PIN_GND = 21;   // UART0 TX, OUTPUT LOW — "fake GND"

// ===== Logicke prahy a casovani =====
constexpr uint32_t WAKE_INTERVAL_S            = 300;     // 5 min 
constexpr float    TILT_THRESHOLD_OPEN        = 60.0f;
constexpr float    TILT_THRESHOLD_CLOSE       = 40.0f;
constexpr int      NIGHT_START_HOUR           = 22; 
constexpr int      NIGHT_END_HOUR             = 6;
constexpr int      HEARTBEAT_HOUR             = 21;
constexpr uint32_t ALERT_RATE_LIMIT_S         = 4 * 60;
constexpr uint32_t ERROR_REPORT_RATE_LIMIT_S  = 30 * 60;   // 30 min — error po chybe nesmi spamovat
constexpr uint32_t NTP_RESYNC_INTERVAL_S      = 24 * 3600;
constexpr uint32_t NTP_OPPORTUNISTIC_INTERVAL_S = 600;
constexpr uint32_t WIFI_TIMEOUT_MS            = 15000;
constexpr uint32_t NTP_TIMEOUT_MS             = 10000;
constexpr uint32_t I2C_TIMEOUT_MS             = 25;        // bus-timeout proti wedged I2C
constexpr uint8_t  MPU_RETRY_COUNT            = 3;
constexpr uint16_t MPU_RETRY_DELAY_MS         = 100;
constexpr uint32_t COLD_BOOT_UPLOAD_WINDOW_S  = 10;        // dev-only; produkce-friendly hodnota

// NTP epoch sanity threshold — vsechny `time()` < tohle se povazuji za "ne-synced".
constexpr time_t   NTP_VALID_EPOCH_THRESHOLD  = 1700000000; // ~ 2023-11-15

// Po N po sobe failnutych WiFi connectech se posila warning notif (pokud se kdy podari).
constexpr uint8_t  WIFI_FAIL_REPORT_THRESHOLD = 3;
// Strop pending error counteru — vyssi hodnoty zafrejzuji v RTC mem.
constexpr uint32_t PENDING_ERROR_COUNT_CAP    = 999;

// LED indikace casovani
constexpr uint32_t LED_INDICATION_MS          = 5000;
constexpr uint32_t LED_BLINK_HALF_PERIOD_MS   = 500;

// Cekani po Serial.begin pred prvnim printf — USB-CDC potrebuje cas na host enumeraci.
constexpr uint32_t SERIAL_INIT_DELAY_MS       = 300;

// Debug switch — false = misto realneho deep sleep jen delay(WAKE_INTERVAL_S).
// USB-CDC zustane connected, logy z kazdeho wake cyklu jsou videt continuously,
// "going to sleep" / "woke up" hlasky se stale printuji (pro vizualni sanity).
// Chip nikdy realne nezaspi → spotreba je ~25 mA continuous, jen pro debug u stolu.
// Pred deploymentem zpet na `true`.
constexpr bool     DEEP_SLEEP_ENABLED         = true;

// CZ timezone (POSIX format) — automaticky resi CET/CEST DST.
// Definice v net.cpp (extern aby slo sdilet pres TU).
extern const char* const TZ_CZ;
extern const char* const NTP_SERVERS[3];

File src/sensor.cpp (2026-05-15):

#include "sensor.h"

#include <Wire.h>
#include <math.h>
#include "config.h"

namespace {

constexpr uint8_t REG_PWR_MGMT_1   = 0x6B;
constexpr uint8_t REG_ACCEL_XOUT_H = 0x3B;
constexpr uint8_t REG_WHO_AM_I     = 0x75;
constexpr float   ACCEL_LSB_PER_G  = 16384.0f;   // ±2g range
constexpr uint8_t PWR_SLEEP_BIT    = 0x40;

bool i2c_write(uint8_t reg, uint8_t val) {
  Wire.beginTransmission(MPU_I2C_ADDR);
  Wire.write(reg);
  Wire.write(val);
  return Wire.endTransmission() == 0;
}

}  // namespace

void mpu_initialize_i2c(uint8_t sda_pin, uint8_t scl_pin) {
  Wire.begin(sda_pin, scl_pin);
  Wire.setClock(400000);
  Wire.setTimeOut(I2C_TIMEOUT_MS);   // bran proti wedged-bus stackingu pres retries
}

bool mpu_wake() {
  if (!i2c_write(REG_PWR_MGMT_1, 0x00)) return false;
  delay(30);  // stabilizace oscilatoru
  return true;
}

bool mpu_sleep() {
  return i2c_write(REG_PWR_MGMT_1, PWR_SLEEP_BIT);
}

uint8_t mpu_who_am_i() {
  Wire.beginTransmission(MPU_I2C_ADDR);
  Wire.write(REG_WHO_AM_I);
  if (Wire.endTransmission(false) != 0) return 0;
  if (Wire.requestFrom(static_cast<uint8_t>(MPU_I2C_ADDR), static_cast<uint8_t>(1)) != 1) return 0;
  return Wire.read();
}

const char* mpu_chip_name(uint8_t who_id) {
  switch (who_id) {
    case 0x68: return "MPU-6050";
    case 0x70: return "MPU-6500";
    case 0x71: return "MPU-9250";
    case 0x73: return "MPU-9255";
    default:   return "neznamy";
  }
}

bool mpu_is_known_chip(uint8_t who_id) {
  return who_id == 0x68 || who_id == 0x70 || who_id == 0x71 || who_id == 0x73;
}

bool mpu_read_accel_raw(int16_t& ax, int16_t& ay, int16_t& az) {
  Wire.beginTransmission(MPU_I2C_ADDR);
  Wire.write(REG_ACCEL_XOUT_H);
  if (Wire.endTransmission(false) != 0) return false;
  if (Wire.requestFrom(static_cast<uint8_t>(MPU_I2C_ADDR), static_cast<uint8_t>(6)) != 6) return false;
  // Explicitni byte-by-byte read (vyhne se neuplnemu evaluation order na operandech
  // |) + cast pres uint16_t pred int16_t (safe sign extension).
  auto read_be16 = []() {
    uint16_t hi = static_cast<uint16_t>(Wire.read());
    uint16_t lo = static_cast<uint16_t>(Wire.read());
    return static_cast<int16_t>((hi << 8) | lo);
  };
  ax = read_be16();
  ay = read_be16();
  az = read_be16();
  return true;
}

bool mpu_measure_avg(uint8_t n_samples, Vec3& out) {
  if (n_samples < 2) return false;
  float sx = 0, sy = 0, sz = 0;
  uint8_t valid = 0;
  for (uint8_t i = 0; i < n_samples; i++) {
    int16_t rx, ry, rz;
    if (!mpu_read_accel_raw(rx, ry, rz)) { delay(10); continue; }
    if (i == 0) { delay(10); continue; }   // prvni vzorek je outlier po wake
    sx += rx / ACCEL_LSB_PER_G;
    sy += ry / ACCEL_LSB_PER_G;
    sz += rz / ACCEL_LSB_PER_G;
    valid++;
    delay(10);
  }
  if (valid == 0) return false;
  out.x = sx / valid;
  out.y = sy / valid;
  out.z = sz / valid;
  return true;
}

const char* orientation_label(const Vec3& a, float& theta_out_deg) {
  float m = vec_mag(a);
  if (!isfinite(m) || m < 1e-6f) { theta_out_deg = 0; return "neznámá"; }
  float c = fabsf(a.z) / m;
  if (c > 1.0f) c = 1.0f;
  theta_out_deg = acosf(c) * 180.0f / static_cast<float>(PI);
  if (theta_out_deg < 25.0f) return "leží naplocho (Z dominantní)";
  if (theta_out_deg > 65.0f) return "stojí vertikálně (X/Y dominantní)";
  return "šikmo";
}

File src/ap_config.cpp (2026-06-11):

#include "ap_config.h"

#include <Arduino.h>
#include <WiFi.h>
#include <WebServer.h>
#include "esp_sleep.h"

#include "config.h"
#include "led.h"
#include "power.h"
#include "storage.h"

namespace {

constexpr uint32_t AP_TIMEOUT_MS         = 10 * 60 * 1000UL;
constexpr uint32_t AP_LED_BURST_PERIOD_MS = 3000;
constexpr uint32_t AP_LED_PULSE_MS        = 100;
constexpr uint8_t  AP_LED_BURST_COUNT     = 3;
constexpr uint32_t WIFI_TEST_TIMEOUT_MS   = 15000;
constexpr uint32_t AP_LOG_HEARTBEAT_MS    = 30000;   // log "still waiting" kazde 30 s

WebServer server(80);

// State pro non-blocking LED triple-blink (3× za 3 s):
//   Trojity blink trva 3 × (on 100 + off 100) = 600 ms, pak pauza 2400 ms.
//   Behem pauzy server svobodne handleClient(). Behem blinku kratky delay
//   blokuje ~600 ms / 3000 ms = 20 % casu — pro form submit akceptovatelne.
uint32_t last_led_burst = 0;

String ap_ssid() {
  uint8_t mac[6];
  WiFi.macAddress(mac);
  char buf[32];
  snprintf(buf, sizeof(buf), "garaz-%02X%02X%02X", mac[3], mac[4], mac[5]);
  return String(buf);
}

// Vygeneruj default ntfy topic z MAC adresy (per-device unikatni).
// Pouziva se jako pre-fill v form polozce pro fresh install. User muze prepsat.
// Format: "garaz-XXXXXX-YYYYYY" (12 hex chars z MAC + chip suffix = ~10^14 kombinaci).
String default_ntfy_topic() {
  uint8_t mac[6];
  WiFi.macAddress(mac);
  char buf[40];
  snprintf(buf, sizeof(buf), "garaz-%02X%02X%02X-%02X%02X%02X",
           mac[0], mac[1], mac[2], mac[3], mac[4], mac[5]);
  return String(buf);
}

void led_ap_tick() {
  uint32_t now = millis();
  if (now - last_led_burst < AP_LED_BURST_PERIOD_MS) return;
  last_led_burst = now;
  for (uint8_t i = 0; i < AP_LED_BURST_COUNT; i++) {
    led_show(0, 0, 80);    // modra
    delay(AP_LED_PULSE_MS);
    led_off();
    delay(AP_LED_PULSE_MS);
  }
}

String html_escape(const String& s) {
  String out;
  out.reserve(s.length() + 16);
  for (size_t i = 0; i < s.length(); i++) {
    char c = s[i];
    switch (c) {
      case '<':  out += "&lt;";   break;
      case '>':  out += "&gt;";   break;
      case '&':  out += "&amp;";  break;
      case '"':  out += "&quot;"; break;
      case '\'': out += "&#39;";  break;   // attributes pouzivame s ' delimitery
      default:   out += c;
    }
  }
  return out;
}

// HTML form. Pri prvnim load NVS prazdny → fieldy default z config.h.
// Pri double-RST: NVS uz vymazano, ale uzivatel mozna chce zachovat stare
// hodnoty. (V soucasnem designu cfg_clear je vola PRED run_ap_mode, takze
// cfg je defaultni — to je OK, user prepis z hlavy nebo z poznamek.)
String build_form_html(const String& wifi_scan_options, const String& status_msg) {
  String h;
  h.reserve(4096);
  h += F("<!DOCTYPE html><html lang=cs><head><meta charset=utf-8>");
  h += F("<meta name=viewport content='width=device-width,initial-scale=1'>");
  h += F("<title>Hlidac vrat — konfigurace</title>");
  h += F("<style>");
  h += F("body{font-family:system-ui,sans-serif;max-width:480px;margin:1em auto;padding:0 1em;color:#222;}");
  h += F("h1{font-size:1.2em;}h2{font-size:1.05em;margin-top:1.5em;border-top:1px solid #ddd;padding-top:1em;}");
  h += F("label{display:block;margin:0.6em 0 0.2em;font-size:0.9em;color:#555;}");
  h += F("input,select{width:100%;padding:0.5em;font-size:1em;box-sizing:border-box;border:1px solid #bbb;border-radius:4px;}");
  h += F("button{margin-top:1.5em;padding:0.8em;width:100%;font-size:1em;background:#0066cc;color:#fff;border:0;border-radius:4px;cursor:pointer;}");
  h += F("button:hover{background:#0055aa;}");
  h += F(".msg{padding:0.6em;border-radius:4px;margin:0.8em 0;}");
  h += F(".err{background:#ffe0e0;border:1px solid #c00;}");
  h += F(".ok{background:#e0ffe0;border:1px solid #0a0;}");
  h += F(".hint{font-size:0.8em;color:#777;margin-top:0.2em;}");
  h += F("</style></head><body>");
  h += F("<h1>Hlídač vrat — konfigurace</h1>");
  if (status_msg.length()) {
    h += status_msg;
  }
  h += F("<form method=POST action='/save'>");

  h += F("<h2>Síť</h2>");
  h += F("<label>WiFi síť (SSID)</label>");
  h += F("<select name=wifi_ssid>");
  h += wifi_scan_options;
  h += F("</select>");
  h += F("<div class=hint>Pokud chybí, zkus znova načíst stránku.</div>");

  h += F("<label>Heslo WiFi</label>");
  h += F("<input id=pwd name=wifi_pass type=password autocomplete=off>");
  h += F("<label style='font-weight:normal;color:#555;cursor:pointer'>");
  h += F("<input type=checkbox style='width:auto;margin-right:.4em;vertical-align:middle' ");
  h += F("onclick=\"var p=document.getElementById('pwd');p.type=this.checked?'text':'password'\"> ");
  h += F("Zobrazit heslo</label>");
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

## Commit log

2026-05-08 Initial PoC: garage door tilt detection with ESP32 + MPU6050 + ntfy.sh
    Detection of garage doors left open at night (22:00-06:00) via accelerometer
    tilt sensing, with battery-powered deep sleep cycle and WiFi push notifications.
    Project structure:
    - src/main.cpp: integrated app (cold boot + 5min wake cycle + alert/heartbeat/error)
    - debug/{tilt,ntfy,sleep}: standalone debug firmwares per concern
    - include/secrets.h.example: WiFi/ntfy template (real secrets.h gitignored)
    - README.md: technical docs (architecture, hardware, measurements, gotchas)
    - USAGE.md: end-user guide (notifications, battery %, FAQ)
    - box.FCStd, box-Body.stl: 3D printable enclosure (FreeCAD source + STL)
    Verified on Fir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
    [box-Body.stl, box.FCStd]
2026-05-08 3d print updated
    [box-Body.stl, box.FCStd]
2026-05-08 fix: TZ env not preserved across deep sleep + minor cleanup
    ESP32 RTC keeps unix time across deep sleep, but TZ env var (set via
    configTzTime / setenv) is reset. Result: localtime_r() returned UTC after
    wake, is_night_window() compared UTC hour against local NIGHT_START_HOUR,
    silently skipping alerts. Now setenv+tzset called every setup() before
    any time logic.
    Also:
    - Add [time] diagnostic log in wake cycle (current hour + night window check)
    - Fix Czech grammar in rssi_label: signál is masculine (vyborna→vyborny etc.)
    [main.cpp]
2026-05-08 feat: opportunistic NTP threshold + MPU retry + reassuring error text
    - NTP sync after WiFi connect now respects 1h threshold (NTP_OPPORTUNISTIC_INTERVAL_S)
    instead of unconditional sync. Prevents NTP spam during stuck-open alerts.
    Forced 24h refresh (NTP_RESYNC_INTERVAL_S) still applies as safety net.
    - MPU wake/measure retried up to 3 times (MPU_RETRY_COUNT) with 100ms delay
    before queueing error. Absorbs transient I²C glitches without false alarms.
    Adds <300ms worst case to wake cycle.
    - Error notification body now includes context-aware reassurance:
    - count==1: "Jednorazova chyba je obvykle OK (I2C glitch)..."
    - count>1: "Chyby se opakuji - pravdepodobne realny problem..."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
    [main.cpp]
2026-05-08 fix: code review findings — NIGHT_HOUR, RTC sentinel, signed elapsed, NaN guard, NTP threshold
    Critical fixes from 5-agent code review:
    1. NIGHT_START_HOUR=13 was leftover test value from debug session — restored to 22
    (alert window now correctly 22:00-06:00 as documented).
    2. RTC mem magic sentinel (STATE_MAGIC = 0xC0FFEE42) protects baseline + state
    from brownout/WDT resets. Previously cause==UNDEFINED triggered do_cold_boot()
    on any non-timer reset, wiping baseline even when RTC mem was preserved.
    Now: cold-boot only if magic invalid; otherwise continue as wake cycle.
    3. Signed elapsed_at_least() helper replaces unsigned subtraction in 4 rate-limit
    checks. Prevents w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
    [main.cpp]
2026-05-08 docs: note time may drift by a few minutes (no RTC crystal)
    Add brief explanation in USAGE.md that displayed time in notifications
    may be off by a couple minutes — board uses internal oscillator, syncs
    every ~10 min via NTP. For 22:00-06:00 night window detection this is
    plenty accurate; sets correct user expectation so they don't worry.
2026-05-10 feat: boot notif shows accel components + orientation hint
    |a|≈1g alone only confirms the sensor responds — it doesn't tell the
    user whether the door was in the expected position at install time.
    Now the boot message reports ax/ay/az, a textual orientation label
    (naplocho / vertikalne / sikmo) with angle from horizontal, and an
    explicit warning that tilt is computed against this baseline so a
    mismatch means open/closed logic will be inverted.
    [main.cpp]
2026-05-12 feat(3dprint): parametric OpenSCAD enclosure for garage-door-notif
    Box for 18650 + ESP module + MPU6050: cradled battery (U-channel + closed
    ring + mirrored lid half-cradle on the open end), screw-on lid with M3
    imbus, garage-door mount holes through the floor, rocker switch slot
    next to USB-C (slides in from above), and zip-tie tunnels through the
    cradle for extra battery retention.
    Includes box.md with the design rationale, parameter dependencies, and
    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
    [box-base.stl, box-lid.stl, box.FCStd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]
2026-05-13 LaskaKit ESP32-C3 bring-up + 3D print refinement + heartbeat uptime
    * 3dprint/new/box.scad: ESP/MPU measurements from real boards
    - ESP mounting hole spacing 16→20, MPU 16→15
    - Single central ESP under-support (Ø4×5 mm, 26 mm from mounts)
    - Single central ESP lid pressure pin (Ø4, 31 mm from mounts, 5.5 mm gap)
    - LED viewing hole (Ø4) in lid above on-board NeoPixel
    * src/main.cpp: daily heartbeat now reports uptime ("Bezi: Xd Yh Zm")
    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
    [box-base.stl, box-lid.stl, box.scad]
2026-05-13 WiFi RSSI test for C3 + antenna mount hole + lifetime analysis
    - debug/c3wifi: connect to AP, log RSSI/channel/IP every 5 s
    (overeni preletovaneho U.FL pigtailu / antenni cesty)
    - 3dprint/new/box.scad: Ø6.2 mm hole in +X wall, aligned with USB-C
    in Y, lifted +5 mm in Z (SMA/RP-SMA bulkhead)
    - README: ESP32-C3 board variants note + wake-interval vs battery
    lifetime projection table
    [box-base.stl, box.scad]
2026-05-15 C3 debug envs (MPU, power, sleep) + measured consumption vs FireBeetle
    - debug/c3mpu: MPU6050/6500 bring-up on SDA=GPIO6, SCL=GPIO7 with
    WHO_AM_I detection (accepts 0x68/0x70/0x71/0x73, per-chip temp formula)
    - debug/c3power: cyclic deep-sleep + WiFi POST for power measurement,
    dual log USB-CDC + UART0 (GPIO20/21), DNS override, RTC mem stats
    - debug/c3sleep: WiFi-less variant for isolated CPU+LED measurement
    - All three honor LaskaKit PERIPH_EN (GPIO4) with gpio_hold_en across
    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
2026-05-15 Modular refactor, UX overhaul, FireBeetle removal, 3dprint tweaks
    C3 firmware refactor:
    - Split src/main.cpp (745 lines) into 8 headers + 7 modules in include/ and src/
    (config, vec3, state, sensor, power, led, net, time_utils, notifications)
    - main.cpp is now pure orchestration: setup, cold_boot, wake_cycle, deep_sleep
    - Clean layered DAG: data → HW → services → domain → orchestration
    - RTC state via extern in state.h, anonymous namespaces for file-local helpers
    User-facing UX fixes:
    - Boot notif: stripped ax/ay/az/|a| jargon, kept orientation + recovery instruction
    - Alert: added "Zkontroluj vrata." CTA, fail-open with "(čas neznámý)" when NTP unsynced
    - Heartbeat: catch-up >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
    [box-base.stl, box-lid.stl, box.FCStd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]
2026-05-15 NVS config + AP setup mode + double-RST / GPIO trigger + extensive USAGE guide
    Persistent configuration via NVS (Preferences) — replaces compile-time secrets
    for WiFi/topic, makes behavior runtime-configurable:
    - New module storage.{h,cpp}: Config struct, cfg_load/save/clear via NVS
    namespace "garaz". Fields: wifi_ssid/pass, ntfy_topic, device_name,
    night_start/end_hour, heartbeat_hour, wake_interval_s. Defaults from
    config.h / secrets.h.
    - net.cpp, time_utils.cpp, notifications.cpp, main.cpp now read runtime
    config from `cfg` instead of compile-time constants. Tilt thresholds and
    WiFi/NTP timeouts stay in config.h (developer-only).
    AP configuration mode (ap_config.{h,cpp}):
    -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
    [ap_config.cpp, config.h, main.cpp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]
2026-05-15 README: trim BOM + drop gotchas/roadmap/debug/todo sections
    BOM cleanup:
    - Drop "Stav" column (mám / hotovo) — not useful for readers
    - Add "Cena" column with current LaskaKit prices (verified via web)
    - Add pigtail (38 Kč) + antenna (88 Kč) rows for external-antenna variant
    - Add screws line (M3 + M2.5, ~20 Kč)
    - Drop DuPont cables — wires soldered directly for vibration resistance
    - Total: ~660 Kč PCB antenna / ~790 Kč external antenna
    Sections removed (cleanup, not relevant for current README scope):
    - Hardware gotchas
    - Budoucí rozšíření (v2)
    - Debug — vývojářské nástroje
    - TODO
    README is now strictly what/how/why; brainstorm / roadmap can move to
    separate docs if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
2026-05-15 docs: add photos of finished box to README + USAGE, fix dimensions
    - imgs/: 5 photos of the finished build (top with antenna+ruler, two
    inside layouts, lid with LED window, angled view with switch)
    - README Hardware section: img1 hero shot (size reference) at top, img2
    inside layout below the MPU wiring table with annotated component
    positions
    - README: prominent block-quote note about the two C3-LPKit variants
    (PCB antenna vs U.FL external) — was buried in BOM cell text before
    - USAGE: img5 in intro (what the device looks like), img4 in LED
    section (visible LED window in lid), img3 in error troubleshooting
    (reference for "open the box and check")
    - Correct enclosure dimensions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
2026-05-15 Remove secrets.h — config is fully runtime via NVS / AP mode
    With NVS-backed Config and AP setup mode, compile-time credentials are
    no longer needed. Fresh install: cfg.configured=false → AP mode → user
    fills form → cfg_save() writes NVS → normal boot. Empty defaults for
    SSID/password/topic in storage.cpp are sufficient.
    - Delete include/secrets.h (gitignored) and include/secrets.h.example
    - Drop .gitignore entry for include/secrets.h
    - storage.cpp: remove #include "secrets.h"; WIFI_SSID/WIFI_PASS/NTFY_TOPIC
    fallbacks replaced with empty string literals
    - main.cpp: update comment about cfg defaults
    - README: drop "## Secrets" section (procedure no longer applies)
    Co-Authored-By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
    [main.cpp, storage.cpp]
2026-05-15 3dprint: flatten — drop legacy FreeCAD files, promote new/ to 3dprint/
    Old structure had stale FreeCAD .FCStd + .FCBak + .stl at 3dprint/ root
    from earlier design iteration, plus working files in 3dprint/new/.
    The "new" subfolder is now the only thing, flatten it:
    - Delete 3dprint/box.FCStd, 3dprint/box-Body.stl (legacy)
    - Delete 3dprint/box.20260507-203806.FCBak (legacy backup, was untracked)
    - Delete box.FCStd at project root (also legacy)
    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
    [box-Body.stl, box-base.stl, box-lid.stl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]
2026-05-15 USAGE: fix NTP sync claim, use RX/TX silkscreen labels for AP trigger pins
    - NTP sync description was wrong ("each ~10 min"). Reality: forced once
    per 24h + opportunistic when WiFi connects for another reason (alert /
    heartbeat / error flush). Typical day = ~1 sync at heartbeat (21:00),
    drift between syncs stays under ~30 s.
    - AP trigger pin instructions reference RX/TX (silkscreen labels) in
    addition to GPIO20/GPIO21 — easier to find on the board.
2026-05-15 3dprint: drop remaining box.FCStd — model is in box.scad only
    [box.FCStd]
2026-05-15 3dprint: sync box.md with current box.scad
    Doc drifted from the actual model during recent SCAD tweaks. Fixes:
    - Battery cradle: 64 mm open + 6 mm ring (was 60+10; `batt_ring_len = 6.0`)
    - Add antenna hole entry: Ø 6.5 mm in +X wall, +5 mm Z above USB-C center
    - Document rocker switch +2 mm Y offset from USB-C center
    - Zip-tie tunnel clearance to lid cradle: ~12.5 mm (was wrongly "~7.5")
    - Add `ant_hole_dia` / `ant_hole_z_lift` to the "How to change" table
2026-05-15 BOM: M2 screws + PETG filament 60g
    - README BOM: M3+M2.5 → M3+M2 screws (matches actual hardware used)
    - README BOM: PLA ~30g → PETG ~60g, price stays ~30 Kč
    (60g × ~0.5 Kč/g for PETG instead of 30g × ~1 Kč/g for PLA)
    - 3dprint/box.md + box.scad: note that pilot 2.1mm is original M2.5
    design but M2 self-tap holds fine in PETG
    - Print notes: PETG used in current build, ~60 g per set
    [box.scad]
2026-06-11 fix(ntp): wait for SNTP_SYNC_STATUS_COMPLETED, not "time is valid"
    ntp_sync() used `time() > NTP_VALID_EPOCH_THRESHOLD` as the success
    condition. After the first cold-boot sync this was always true (RTC
    keeps a valid timestamp across deep sleep), so subsequent calls returned
    immediately without waiting for a fresh SNTP response. configTzTime
    did kick off a background daemon, but the polling loop bailed before
    it had a chance to update the time. Result: chip-only drift (~150 ppm
    on ESP32-C3 internal RC = ~7 min / month, matching the field report).
    Fix: reset sntp_set_sync_status(RESET) before configTzTime, then poll
    sntp_get_sync_status() until COMPLETED — that flag only flips in the
    SNTP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
    [box-base.stl, box-lid.stl, box.scad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]
2026-06-11 Code review HIGH fixes + show-password toggle in AP form
    NTP sync, round 2 (net.cpp):
    - Add `sntp_stop()` before `configTzTime()`. The previous fix reset the
    status flag but `sntp_init()` is a no-op if the daemon is already
    running — so no fresh query was sent and ntp_sync would timeout
    silently. Now the daemon restarts and a real network query goes out.
    NVS torn-write defence (storage.cpp):
    - After cfg_load, if `configured=true` but wifi_ssid or ntfy_topic is
    empty, force `configured=false`. Protects against power-loss mid-save
    leaving NVS in an inconsistent state where the device would otherwise
    enter normal boot with broken creds and infinite WiFi-fail loop.
    AP form input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
    [ap_config.cpp, net.cpp, storage.cpp]
